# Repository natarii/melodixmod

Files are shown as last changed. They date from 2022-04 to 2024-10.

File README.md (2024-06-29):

MelodixMod
========
The MelodixMod project adds internal memory to the TOA MELODIX ML-304 melody generator. This repository also contains WIP hardware and software documentation for the original device.

## Overview
ML-304 devices use a Yamaha YM2203 OPN FM sound source to play back melodies, chimes and tones stored on memory cards. The MelodixMod system serves as an effective replacement for these cards. Full function of the original unit is retained -- physical cards inserted into the slots will override any data stored on MelodixMod's flash. A bank switching option is available through a hole on the rear panel which allows the user to switch between multiple banks of simulated cards. Impact to the device's appearance is also minimized, with the only change visible from the outside being the removal of a grounding screw.

### Mod Files
- `Logic` - Data to program the mod's decode logic chip
- `MCU` - Program for the mod's ATTiny85 MCU
- `PCB` - EAGLE schematic and PCB design files
- `PCBSpacer` - OpenSCAD design file and STL for a 3D-printable spacer to support the mod PCB

### Research Files
- `Disassembly` - Original ML-304 program disassembly
- `FujisokuBProgrammer` Arduino Mega-based programmer for Melodix cards
- `MelodixCard` - Information about the data format on Melodix cards




## MELODIX CARD information

The memory cards used in the ML-304 are pre-programmed and follow the Fujisoku B-series physical and electrical standard. Despite a very vague resemblance to PCMCIA and other common memory cards, this is an obsolete and relatively rare format. As the Melodix units are niche in addition to not having been marketed outside of Japan, original TOA cards fetch prices in the hundreds of USD range on auction sites, making it infeasible for most (certainly me!) to collect any more than the less-desirable cards.

## Why making reproduction cards isn't viable

Fujisoku B-series cards use very thin contacts on the card side, which mate with "forks" in the slot. A reproduction card could likely be made out of very thin PCB, but there is not much remaining height for components on the board. Surface mount parts may be viable (assuming a programmer which the cards could slot into existed -- more on that later), but any through-hole parts like socketed memory would not be usable without hanging further than usual out of the front of the device (outside of the normal card form factor).

UV EPROM, EEPROM, flash, and SRAM-based B-series cards were produced, but these are also becoming increasingly difficult to find. As these cards are writable, they also require hardware modifications to the Melodix unit as it does not drive all of the control lines they need.

## Card slot availability

In 2021, the availability of B-series card slots was essentially nil. An exhaustive personal and crowdsourced search turned up no supplies of slots, aside from ones that could be removed from an existing piece of equipment. I was also not able to establish an actual part number or manufacturer for the slots.

In 2023, some slots have turned up on US eBay. I also found further documentation which reveals some card slot part numbers, which are listed below. Note that not all of these are usable as replacements in the original device, but could be used in an external programmer or dumping tool.

- ITT Cannon 990-2000-053 (right angle pins)
- ITT Cannon DICMI-38S-RPC-01 (right angle pins)
- Hakuto BC1R (right angle pins)
- Hakuto BC1S (straight pins)

Regardless of any current availability of card slots, they are no longer being produced and supplies will eventually run out. This is another nail in the coffin for using the programmable variants as reproduction cards.

## I made a reproduction card anyway

Before deciding to proceed with an internal card modification, I ended up purchasing an SRAM card and designing an Arduino Mega-based programmer for it. The programmer can connect to the Mega board with no extra components needed, and the code allows for card memory to be uploaded and downloaded via XMODEM. I also performed the required modifications to the Melodix PCB to allow SRAM cards to be used.

It is also possible to adapt these cards to be used in a standard EPROM programmer.

## Related WIP projects / TODO

  * Verify v1.1 mod PCB
  * Disassembly of ML-304/ML-301 MCU program (nearly complete, needs some updates now that I have the hardware to reference, also needs to be done in proper f9dasm format rather than simple text find-and-replace)
  * MAME driver for Melodix series (working, needs better integration with MAME cartridge system, needs UI)
  * Melodix card to VGM conversion utility (working, needs cleanup but otherwise complete)
  * MIDI to Melodix card conversion utility (partially working)
  * Replacement main MCU (not started)
  * Document the process to prepare data for MelodixMod's flash (really just concatenate 32KByte binaries)

## Acknowledgements
  * Thanks to Hind for providing the initial MCU ROM dump.

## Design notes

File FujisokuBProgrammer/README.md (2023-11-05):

This is a very quick and dirty program to be used with an Arduno Mega which allows reading and writing memory cards using XMODEM.

Wiring diagram can be divined from the code. Open the serial port at 115200 baud and issue the '?' character for usage information.

Please be cautious when using this tool as some commands will permanently destroy data without any warning or confirmation.

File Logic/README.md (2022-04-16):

A dedicated flash IC is used to implement chip select and bank switching logic.

A pre-built flash image is included, but a new one can be built using the PHPPLD project. This image is generated for up to 4 megabit flash, but can be written (with the higher unused area ignored) to 1 and 2 megabit parts.

`php <path to PHPPLD> -i 19 -w logic.bin logic.php`

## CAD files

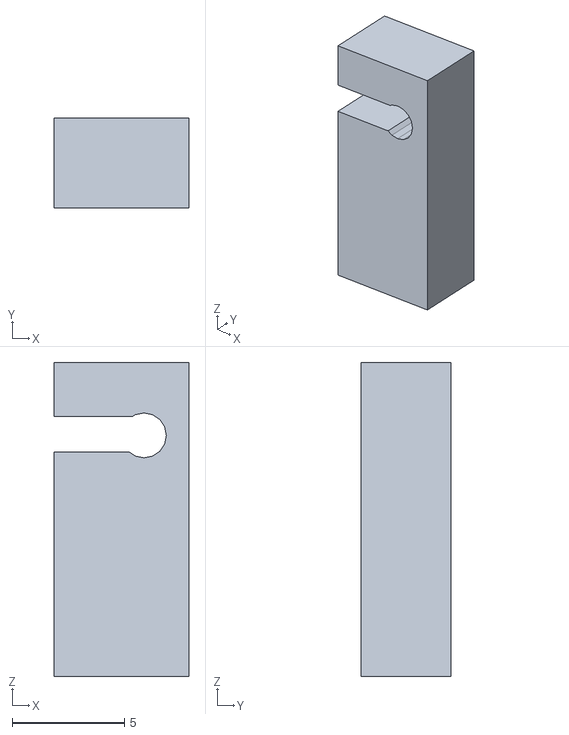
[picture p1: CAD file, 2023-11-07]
PCBSpacer/MelodixModPCBSpacer.stl
6.00 x 4.00 x 14.0

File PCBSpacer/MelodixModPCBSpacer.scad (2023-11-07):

$fn = 16;
difference() {
    union() {
        cube([6,4,10]);
        translate([0,0,10]) cube([6,4,4]);
    }
    translate([0,0,10]) cube([4,4,1.6]);
    translate([4,0,10.75]) rotate([-90,0,0]) cylinder(r=1, h=99, center=true);
}

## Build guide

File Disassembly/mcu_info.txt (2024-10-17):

*f9dasm base config
option 6301
file mcu.bin f000

*regions
data f000-f015 *scale lut
hex f000-f015
const f19a-f19b
const f1ae-f1af
const f210-f211
const f23d-f23e
const f259-f25a
const f272-f273
const f28b-f28c
const f2a4-f2a5
const f2bd-f2be
const f2d6-f2d7
const f382-f383
const f398-f399
const f3b0-f3b1
const f3fe-f3ff
const f8bd-f8be
const f983-f984
const f978-f979
const f9f7-f9f8
const fa1d-fa1e
const fa4b-fa4c
unused fbfb-fcff
word fd00-fd03 *ml301 tune addrs
data fd04-fd35 *ml301 tune patches
word fd36-fd3b *ml301 4-note chime patch addrs
word fd3c-fd41 *ml301 4-note chime track addrs
data fd42-fd75 *ml301 4-note chime track data
word fd76-fd7b *ml301 westminster patch addrs
word fd7c-fd81 *ml301 westminster track addrs
data fd82-fea5 *ml301 westminster track data
unused fea6-ffef

*labels
*mcu internal periphs
label 0000 DDR1
label 0001 DDR2
label 0002 PORT1
label 0003 PORT2
label 0004 DDR3
label 0005 DDR4
label 0007 PORT4
label 0008 TIMERCTL
label 0009 TIMERCNTHI
label 000a TIMERCNTLO *not used
label 000b TIMEROCRHI *not used
label 000d INTCAPHI *not used
label 000f PORT3CTL *not used
label 0010 RATEMODECTL *not used
label 0014 RAMCTL *not used
*vars
label 0080 track1_loc_word
label 0082 track2_loc_word
label 0084 track3_loc_word
label 0086 opn_ch
label 0087 track1_is_finished
label 0088 track2_is_finished
label 0089 track3_is_finished
label 008a opn_timer_b
label 008c track1_note_len
label 008d track2_note_len
label 008e track3_note_len
label 008f track1_kon_len
label 0090 track2_kon_len
label 0091 track3_kon_len
label 0092 patch_upload_tmp
label 0093 fb_algo_base
label 0096 tl_op1_base
label 0099 tl_op2_base
label 009c tl_op3_base
label 009f tl_op4_base
label 00a2 tl_op1
label 00a3 tl_op2
label 00a4 tl_op3
label 00a5 tl_op4
label 00a6 cur_note_freq
label 00a7 unused1
label 00a8 opn_tl_modifier
label 00a9 card_pointer
label 00ab opn_io_a_val
label 00ac active_card_slot
label 00ad tune_repeat_count
label 00ae tune_repeat_delay
label 00af tune_end_repeat_counter
label 00b0 tune_end_delay
label 00b1 patch_loc_word
label 00b3 int_flag
label 00b4 already_playing
label 00b5 currently_playing_bitfield
label 00b6 pressed_switch_bitfield
label 00b7 port1_isr_tmp
label 00b8 nothing_pressed_in_isr
label 00b9 tune_found_ff_flag
label 00ba unk_M00BA
label 00bc ml301_tune_rd_addr
label 00be ml301_is_4note
label 0100 opn_reg
label 0101 ml304_card_d_data_ml301_opn_data
label 0102 card_c_data
label 0103 card_b_data
label 0104 card_a_data
label 0105 card_addr
label 0140 opn_data
*code
label f000 scale_lut
label f05a mainloop
label f0b4 sel_card_at_104
label f0cf sel_card_at_103
label f0ed sel_card_at_102
label f10b sel_card_at_101
label f129 sel2_card_at_104
label f147 sel2_card_at_103
label f165 sel2_card_at_102
label f183 sel2_card_at_101
label f460 stop_track
label f490 opn_write
label f4af opn_read
label f4cb read_tune_data
label f6d2 load_ch_patch
label f565 opn_write_4op_tl
label f5c8 opn_keyon
label f5d2 opn_keyoff
label f5dc opn_write_freq
label f604 opn_timerb_setup
label f648 ml304_setup_next_note_trk1
label f68f ml304_setup_next_note_trk2
label f6d6 ml304_setup_next_note_trk3
label f71d add_opn_ch_x
label f72a spin_delay_100ms
label f7c0 isr_swi3_exit
label f7c9 isr_swi3_nothing_pressed
label f830 ml301_mode
label f869 ml301_clear
label f8bc ml301_setup_tune
label f954 ml301_setup_westminster
label f977 ml301_setup_westminster_2s_delay
label f982 ml301_setup_westminster_4s_delay
label fb2e ml301_setup_next_note_trk1
label fb5d ml301_setup_next_note_trk2
label fb8c ml301_setup_next_note_trk3
label fbbb ml301_swi_isr
label fd00 ml301_4notechime_addr
label fd02 ml301_westminster_addr
label fd04 ml301_4notechime_patch
label fd1d ml301_westminster_patch
label fd36 ml301_4notechime_data
label fd4a ml301_4notechime_trk1
label fd5a ml301_4notechime_trk2
label fd66 ml301_4notechime_trk3
label fd76 ml301_westminster_data
label fd8a ml301_westminster_trk1
label fde6 ml301_westminster_trk2
label fe46 ml301_westminster_trk3

*comments
*vars
lcomment 000a-0014 not used
lcomment 0096-009f note: stored in order 1234 here!!!
lcomment 00a2-00a5 note: stored in order 1234 here!!!
lcomment 00b6 really just a backup of PORT1
lcomment 00b9 can use FF instead of FE to terminate tune?
lcomment 00ba some temp var, holds a backup of X, -> 00BB
lcomment 0101 actually opn data on ml301 (different memory map)
lcomment 0105 16 bit wide, big endian, latched on hardware
lcomment 0140 MCU A6 -> OPN A0 on hardware
*code
lcomment f018 ml-304 bit
lcomment f034 prescaler
lcomment f03b ssg enable
lcomment f03e probably all off 1111
lcomment f042 io a
lcomment f063 redundant, it is written before reading in swi isr
lcomment f1a1 card presence detect
lcomment f1b3 enable TOI
lcomment f1bb io a
lcomment f1c3 mux select
lcomment f1cb mux select
lcomment f1ce card header
lcomment f1d3 relay off
lcomment f1d6 jmp skip start delay
lcomment f1d9 relay on
lcomment f1dc io b
lcomment f1de read start delay bits
lcomment f23c track 1 loc
lcomment f258 patch 1 loc
lcomment f271 track 2 loc
lcomment f28a patch 2 loc
lcomment f2a3 track 3 loc
lcomment f2bc patch 3 loc
lcomment f2d5 timer B val
lcomment f2e7 write timer A/B control and 3ch mode
lcomment f378 clear timer b flag, stop timer b
lcomment f3d6 probably all off 1111
lcomment f3da io a
lcomment f3dd disable TOI
lcomment f3fa write timer A/B control and 3ch mode
lcomment f40c probably all off 1111
lcomment f410 io a
lcomment f413 disable TOI
lcomment f41d big tree to check if trying to play same card already playing?
lcomment f477 write timer A/B control and 3ch mode
lcomment f47a probably all off 1111
lcomment f47e io a
lcomment f481 disable TOI
lcomment f4a3 bra if ml301
lcomment f4c1 bra if ml301
lcomment f4e1 drt/mul
lcomment f4fc write algo+fb
lcomment f504 first tl in patch (patch loc + 4)
lcomment f52c fb/algo (patch loc + 0x18)
lcomment f56d all of these CMPAs are to write TL only for slot operators
lcomment f5ac BUG!!! should be $44
lcomment f5df shl a <- b
lcomment f5eb x+=b
lcomment f5f1 a+=b
lcomment f5f6 freq hi
lcomment f600 freq lo
lcomment f608 a = ff - timerb
lcomment f60b a /= 8
lcomment f610 a = io port b
lcomment f613 a >>= 1
lcomment f614 a &= 0xf
lcomment f618 bra rts
lcomment f61e bra use normal value
lcomment f62f bra write A
lcomment f63e bra write A
lcomment f640 use normal value
lcomment f642 write A
lcomment f644 timer b
lcomment f73e clear timer b flag
lcomment f744 bra if ml301
lcomment f77e bra if ml304
lcomment f78b bra if nothing pressed
lcomment f7c0-f7c2 clear TOF
lcomment f827 all bra here if selected card is already playing?
lcomment f846 prescaler
lcomment f84d ssg enable
lcomment f854 io a
lcomment f8b4 io a
lcomment f8c1 enable TOI
lcomment f941 io a
lcomment f947 io b
lcomment f9ef timer ab ctl 3ch mode
lcomment f9f6 post-westminster delay
lcomment fa13 io a
lcomment fa16 disable TOI
lcomment fa47 timer ab ctl 3ch mode
lcomment fa57 io a
lcomment fa5a disable TOI
lcomment fa84 dt/mul
lcomment fa9b fb/conn
lcomment faf5 reading tempo here for ml301
lcomment fb2a timer b
lcomment fbcc-fbce clear TOF
lcomment fd04 same patch for all three tracks
lcomment fd1d same patch for all three tracks

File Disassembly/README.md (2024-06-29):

**Note:** `mcu.asm` is a generated file. Labels, comments, etc are configured in mcu_info.txt and then the f9dasm program is used to generate the disassembly from the info file and MCU ROM dump. You can generate the disassembly using the following command: `f9dasm -out mcu.asm -info mcu_info.txt`

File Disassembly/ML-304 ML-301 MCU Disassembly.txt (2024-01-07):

./f9dasm -offset f000 -6301  ../TOA\ Melodix/ML-30x\ Series/MCU/HD63B01V1P.bin > mcu.txt

vectors:
FFFE    !RES    F018
FFEE    TRAP    FFFF
FFFC    !NMI    F018
FFFA    SWI     F018
FFF8    !IRQ    F737
FFF6    ICF     F018
FFF4    OCF     F018
FFF2    TOF     F77B
FFF0    SCI     F018

opn and mcu clock is shared 4mhz, xtal + 74'04
mcu has a divide-by-4 internally

opn io:
a:
7 unused
6 unused
5 unused
4 unused
3 ML304B card A LED
2 ML304B card B LED
1 ML304B card C LED, ML301B chime LED
0 ML304B card D LED, ML301B westminster LED
(all active low on mcu, inverted on hw)
b:
7 0sec startup delay, active low
6 2sec startup delay, active low
5 4sec startup delay, active low
4 tempo MSbit
3 tempo
2 tempo
1 tempo LSbit
0 unknown
tempo is inverted on ml301, normal on ml304. valid range 0~9, 5 is normal
other hardware selects which tempo control to use on ml304. selected by the "LED" lines

mcu ports:
port1:
(used for switches, both front panel switch and rear inputs are on this port, unknown yet which switch is which bit)
ml304: all input
ml301: bits 6~4 are output...
active low
on ml301, bit 0 needs to be set and bit 7 needs to be clear to prevent it starting immediately. then bit 0 selects westminster and 1 selects 4note chime
00001011 makes it not play anything
7 ML304 front panel switch A
6 ML304 front panel switch B
5 ML304 front panel switch C
4 ML304 front panel switch D
3 ML304 rear terminal D
2 ML304 rear terminal C
1 ML304 rear terminal B
0 ML304 rear terminal A

port2:
7 unused
6 unused
5 unused
4 unused
3 remote relay, active high
2 volume mux B
1 unused
0 volume mux A
mux card select values:
card A: 3
card B: 0
card C: 1
card D: 2
port4:
7 high = ml304 mode, low = ml301
6 unused
5 unused
4 unused
3 unused
2 unused
1 unused
0 unused

mysteries:
- 0 second start delay jumper is unknown on ml301, but 99.9% bit 7
- options byte at start of card - might control remote relay behavior - MC-S01 has no delay no matter settings
  - bit 1 NOT set = no startup delay, no relay
  - bit 7 NOT set = will not play card. card detect, since the bus is pulled up on hardware?
- how are empty card slots detected? just bit 7 of first byte?
- port1 on ml304 split for front panel switch vs rear switch input, or something like that? which is which?
- ml301 port1 switch confusion
- ml301 port1 bits 6~4 are output... used for anything?

f9dasm: M6800/1/2/3/8/9 / H6309 Binary/OS9/FLEX9 Disassembler V1.80
Loaded binary file ../TOA Melodix/ML-30x Series/MCU/HD63B01V1P.bin

;****************************************************
;* Used Labels                                      *
;****************************************************

DDR1   EQU     $0000
DDR2   EQU     $0001
PORT1   EQU     $0002
PORT2   EQU     $0003
DDR3   EQU     $0004
DDR4   EQU     $0005
PORT4   EQU     $0007
TIMERCTL   EQU     $0008
TIMERCNTHI   EQU     $0009
TIMERCNTLO   EQU     $000A
TIMEROCRHI   EQU     $000B ;not used
INTCAPHI   EQU     $000D ;not used
PORT3CTL   EQU     $000F ;not used
RATEMODECTL   EQU     $0010 ;not used
RAMCTL   EQU     $0014 ;not used
track1_loc_word   EQU     $0080
track2_loc_word   EQU     $0082
track3_loc_word   EQU     $0084
opn_ch   EQU     $0086
track1_is_finished   EQU     $0087
track2_is_finished   EQU     $0088
track3_is_finished   EQU     $0089
opn_timer_b   EQU     $008A
M008B   EQU     $008B
track1_note_len   EQU     $008C
track2_note_len   EQU     $008D
track3_note_len   EQU     $008E
track1_kon_len   EQU     $008F
track2_kon_len   EQU     $0090
track3_kon_len   EQU     $0091
patch_upload_tmp   EQU     $0092
fb_algo_base   EQU     $0093
tl_op1_base   EQU     $0096 ;note: stored in order 1234 here!!!
tl_op2_base   EQU     $0099
tl_op3_base   EQU     $009C
tl_op4_base   EQU     $009F
tl_op1   EQU     $00A2 ;note: stored in order 1234 here!!!
tl_op2   EQU     $00A3
tl_op3   EQU     $00A4
tl_op4   EQU     $00A5
cur_note_freq   EQU     $00A6
unused1   EQU     $00A7
opn_tl_modifier   EQU     $00A8
card_pointer   EQU     $00A9
opn_io_a_val   EQU     $00AB
active_card_slot   EQU     $00AC
tune_end_delay   EQU     $00AD
tune_end_delay_lo   EQU     $00AE
M00AF   EQU     $00AF
M00B0   EQU     $00B0 ;high byte of patch 1 loc???
patch_loc_word   EQU     $00B1
int_flag   EQU     $00B3
already_playing   EQU     $00B4
currently_playing_bitfield   EQU     $00B5
pressed_switch_bitfield   EQU     $00B6 ;really just a backup of PORT1
port1_isr_tmp   EQU     $00B7
nothing_pressed_in_isr   EQU     $00B8
tune_found_ff_flag   EQU     $00B9 ;can use FF instead of FE to terminate tune?
unk_M00BA   EQU     $00BA ;some temp var, holds a backup of X, -> 00BB
unk_M00BC   EQU     $00BC ;temp, stores offset into builtin tune or something like that
unk_M00BE   EQU     $00BE ;temp, some offset on ml301
M00BF   EQU     $00BF
M00C0   EQU     $00C0
M00C1   EQU     $00C1
M00FE   EQU     $00FE
M00FF   EQU     $00FF
opn_reg   EQU     $0100
card_d_data   EQU     $0101
card_c_data   EQU     $0102
card_b_data   EQU     $0103
card_a_data   EQU     $0104
card_addr   EQU     $0105 ;16 bit wide, big endian ($0106 is LSB). must be latched on hardware? (address ON the card)
opn_data_ml304   EQU     $0140 ;MCU A6 -> OPN A0 on hardware??? or something more complicated?

;****************************************************
;* Program Code / Data Areas                        *
;****************************************************

        ORG     $F000

scale_lut   FCB     $02                      ;F000: 02             '.' ;ignore all of this code up to $F017, none of it is valid code, it's just a LUT
        BSR     ZF005                    ;F001: 8D 02          '..'
        ANDA    M02DD                    ;F003: B4 02 DD       '...'
        FCB     $03                      ;F006: 03             '.'
        DEX                              ;F007: 09             '.'
        FCB     $03                      ;F008: 03             '.'
        PSHB                             ;F009: 37             '7'
        FCB     $03                      ;F00A: 03             '.'
        ASL     $03,X                    ;F00B: 68 03          'h.'
        CPX     PORT2                    ;F00D: 9C 03          '..'
        ADDD    DDR3                    ;F00F: D3 04          '..'
        SEC                              ;F011: 0D             '.'
        LSRD                             ;F012: 04             '.'
        FCB     $4B                      ;F013: 4B             'K'
        LSRD                             ;F014: 04             '.'
        CPX     #M04D1                   ;F015: 8C 04 D1       '...'
hdlr_RST TIM     #$80,PORT4               ;F018: 7B 80 07       '{..' ml-304 bit
        BNE     ZF020                    ;F01B: 26 03          '&.'
        JMP     ml301_mode                    ;F01D: 7E F8 30       '~.0'
ZF020   CLRA                             ;F020: 4F             'O'
        STAA    PORT1                    ;F021: 97 02          '..'
        STAA    PORT2                    ;F023: 97 03          '..'
        STAA    DDR1                    ;F025: 97 00          '..'
        LDAA    #$0D                     ;F027: 86 0D          '..'
        STAA    DDR2                    ;F029: 97 01          '..'
        LDAA    #$7F                     ;F02B: 86 7F          '..'
        STAA    DDR4                    ;F02D: 97 05          '..'
        LDS     #M00FF                   ;F02F: 8E 00 FF       '...'
        LDAB    #$2D                     ;F032: C6 2D          '.-'
        JSR     opn_write                    ;F034: BD F4 90       '...' prescaler
        LDAB    #$07                     ;F037: C6 07          '..'
        LDAA    #$7F                     ;F039: 86 7F          '..'
        JSR     opn_write                    ;F03B: BD F4 90       '...' ssg enable
        LDAA    #$0F                     ;F03E: 86 0F          '..' probably all off 1111
        LDAB    #$0E                     ;F040: C6 0E          '..'
        JSR     opn_write                    ;F042: BD F4 90       '...' io a
        CLRA                             ;F045: 4F             'O'
        STAA    opn_ch                    ;F046: 97 86          '..'
        JSR     opn_keyoff                    ;F048: BD F5 D2       '...'
        INC     >opn_ch                   ;F04B: 7C 00 86       '|..'
        JSR     opn_keyoff                    ;F04E: BD F5 D2       '...'
        INC     >opn_ch                   ;F051: 7C 00 86       '|..'
        JSR     opn_keyoff                    ;F054: BD F5 D2       '...'
        AIM     #$F7,PORT2               ;F057: 71 F7 03       'q..'
mainloop   CLRA                             ;F05A: 4F             'O'
        STAA    int_flag                    ;F05B: 97 B3          '..'
        STAA    already_playing                    ;F05D: 97 B4          '..'
        STAA    currently_playing_bitfield                    ;F05F: 97 B5          '..'
        STAA    pressed_switch_bitfield                    ;F061: 97 B6          '..'
        STAA    port1_isr_tmp                    ;F063: 97 B7          '..' redundant, it is written before reading in swi isr
        STAA    nothing_pressed_in_isr                    ;F065: 97 B8          '..'
        STAA    tune_found_ff_flag                    ;F067: 97 B9          '..'
        TIM     #$80,PORT1               ;F069: 7B 80 02       '{..'
        BNE     ZF071                    ;F06C: 26 03          '&.'
        JMP     ZF11E                    ;F06E: 7E F1 1E       '~..'
ZF071   TIM     #$01,PORT1               ;F071: 7B 01 02       '{..'
        BNE     ZF079                    ;F074: 26 03          '&.'
        JMP     ZF0AC                    ;F076: 7E F0 AC       '~..'
ZF079   TIM     #$40,PORT1               ;F079: 7B 40 02       '{@.'
        BNE     ZF081                    ;F07C: 26 03          '&.'
        JMP     ZF13C                    ;F07E: 7E F1 3C       '~.<'
ZF081   TIM     #$02,PORT1               ;F081: 7B 02 02       '{..'
        BNE     ZF089                    ;F084: 26 03          '&.'
        JMP     ZF0C7                    ;F086: 7E F0 C7       '~..'
ZF089   TIM     #$20,PORT1               ;F089: 7B 20 02       '{ .'
        BNE     ZF091                    ;F08C: 26 03          '&.'
        JMP     ZF15A                    ;F08E: 7E F1 5A       '~.Z'
ZF091   TIM     #$04,PORT1               ;F091: 7B 04 02       '{..'
        BNE     ZF099                    ;F094: 26 03          '&.'
        JMP     ZF0E2                    ;F096: 7E F0 E2       '~..'
ZF099   TIM     #$10,PORT1               ;F099: 7B 10 02       '{..'
        BNE     ZF0A1                    ;F09C: 26 03          '&.'
        JMP     ZF178                    ;F09E: 7E F1 78       '~.x'
ZF0A1   TIM     #$08,PORT1               ;F0A1: 7B 08 02       '{..'
        BNE     ZF0A9                    ;F0A4: 26 03          '&.'
        JMP     ZF100                    ;F0A6: 7E F1 00       '~..'
ZF0A9   JMP     mainloop                    ;F0A9: 7E F0 5A       '~.Z'
ZF0AC   JSR     spin_delay_100ms                    ;F0AC: BD F7 2A       '..*'
        TIM     #$01,PORT1               ;F0AF: 7B 01 02       '{..'
        BNE     mainloop                    ;F0B2: 26 A6          '&.'
sel_card_at_104   LDX     #card_a_data                   ;F0B4: CE 01 04       '...'
        STX     card_pointer                    ;F0B7: DF A9          '..'
        LDAA    #$07                     ;F0B9: 86 07          '..' 0111
        STAA    opn_io_a_val                    ;F0BB: 97 AB          '..'
        LDAA    #$00                     ;F0BD: 86 00          '..'
        STAA    active_card_slot                    ;F0BF: 97 AC          '..'
        OIM     #$01,pressed_switch_bitfield               ;F0C1: 72 01 B6       'r..'
        JMP     ZF196                    ;F0C4: 7E F1 96       '~..'
ZF0C7   JSR     spin_delay_100ms                    ;F0C7: BD F7 2A       '..*'
        TIM     #$02,PORT1               ;F0CA: 7B 02 02       '{..'
        BNE     mainloop                    ;F0CD: 26 8B          '&.'
sel_card_at_103   LDX     #card_b_data                   ;F0CF: CE 01 03       '...'
        STX     card_pointer                    ;F0D2: DF A9          '..'
        LDAA    #$0B                     ;F0D4: 86 0B          '..' 1011
        STAA    opn_io_a_val                    ;F0D6: 97 AB          '..'
        LDAA    #$03                     ;F0D8: 86 03          '..'
        STAA    active_card_slot                    ;F0DA: 97 AC          '..'
        OIM     #$02,pressed_switch_bitfield               ;F0DC: 72 02 B6       'r..'
        JMP     ZF196                    ;F0DF: 7E F1 96       '~..'
ZF0E2   JSR     spin_delay_100ms                    ;F0E2: BD F7 2A       '..*'
        TIM     #$04,PORT1               ;F0E5: 7B 04 02       '{..'
        BEQ     sel_card_at_102                    ;F0E8: 27 03          ''.'
        JMP     mainloop                    ;F0EA: 7E F0 5A       '~.Z'
sel_card_at_102   LDX     #card_c_data                   ;F0ED: CE 01 02       '...'
        STX     card_pointer                    ;F0F0: DF A9          '..'
        LDAA    #$0D                     ;F0F2: 86 0D          '..' 1101
        STAA    opn_io_a_val                    ;F0F4: 97 AB          '..'
        LDAA    #$01                     ;F0F6: 86 01          '..'
        STAA    active_card_slot                    ;F0F8: 97 AC          '..'
        OIM     #$04,pressed_switch_bitfield               ;F0FA: 72 04 B6       'r..'
        JMP     ZF196                    ;F0FD: 7E F1 96       '~..'
ZF100   JSR     spin_delay_100ms                    ;F100: BD F7 2A       '..*'
        TIM     #$08,PORT1               ;F103: 7B 08 02       '{..'
        BEQ     sel_card_at_101                    ;F106: 27 03          ''.'
        JMP     mainloop                    ;F108: 7E F0 5A       '~.Z'
sel_card_at_101   LDX     #card_d_data                   ;F10B: CE 01 01       '...'
        STX     card_pointer                    ;F10E: DF A9          '..'
        LDAA    #$0E                     ;F110: 86 0E          '..' 1110
        STAA    opn_io_a_val                    ;F112: 97 AB          '..'
        LDAA    #$02                     ;F114: 86 02          '..'
        STAA    active_card_slot                    ;F116: 97 AC          '..'
        OIM     #$08,pressed_switch_bitfield               ;F118: 72 08 B6       'r..'
        JMP     ZF196                    ;F11B: 7E F1 96       '~..'
ZF11E   JSR     spin_delay_100ms                    ;F11E: BD F7 2A       '..*'
        TIM     #$80,PORT1               ;F121: 7B 80 02       '{..'
        BEQ     sel2_card_at_104                    ;F124: 27 03          ''.'
        JMP     mainloop                    ;F126: 7E F0 5A       '~.Z'
sel2_card_at_104   LDX     #card_a_data                   ;F129: CE 01 04       '...'
        STX     card_pointer                    ;F12C: DF A9          '..'
        LDAA    #$07                     ;F12E: 86 07          '..' 0111
        STAA    opn_io_a_val                    ;F130: 97 AB          '..'
        LDAA    #$00                     ;F132: 86 00          '..'
        STAA    active_card_slot                    ;F134: 97 AC          '..'
        OIM     #$80,pressed_switch_bitfield               ;F136: 72 80 B6       'r..'
        JMP     ZF196                    ;F139: 7E F1 96       '~..'
ZF13C   JSR     spin_delay_100ms                    ;F13C: BD F7 2A       '..*'
        TIM     #$40,PORT1               ;F13F: 7B 40 02       '{@.'
        BEQ     sel2_card_at_103                    ;F142: 27 03          ''.'
        JMP     mainloop                    ;F144: 7E F0 5A       '~.Z'
sel2_card_at_103   LDX     #card_b_data                   ;F147: CE 01 03       '...'
        STX     card_pointer                    ;F14A: DF A9          '..'
        LDAA    #$0B                     ;F14C: 86 0B          '..' 1011
        STAA    opn_io_a_val                    ;F14E: 97 AB          '..'
        LDAA    #$03                     ;F150: 86 03          '..'
        STAA    active_card_slot                    ;F152: 97 AC          '..'
        OIM     #$40,pressed_switch_bitfield               ;F154: 72 40 B6       'r@.'
        JMP     ZF196                    ;F157: 7E F1 96       '~..'
ZF15A   JSR     spin_delay_100ms                    ;F15A: BD F7 2A       '..*'
        TIM     #$20,PORT1               ;F15D: 7B 20 02       '{ .'
        BEQ     sel2_card_at_102                    ;F160: 27 03          ''.'
        JMP     mainloop                    ;F162: 7E F0 5A       '~.Z'
sel2_card_at_102   LDX     #card_c_data                   ;F165: CE 01 02       '...'
        STX     card_pointer                    ;F168: DF A9          '..'
        LDAA    #$0D                     ;F16A: 86 0D          '..' 1101
        STAA    opn_io_a_val                    ;F16C: 97 AB          '..'
        LDAA    #$01                     ;F16E: 86 01          '..'
        STAA    active_card_slot                    ;F170: 97 AC          '..'
        OIM     #$20,pressed_switch_bitfield               ;F172: 72 20 B6       'r .'
        JMP     ZF196                    ;F175: 7E F1 96       '~..'
ZF178   JSR     spin_delay_100ms                    ;F178: BD F7 2A       '..*'
        TIM     #$10,PORT1               ;F17B: 7B 10 02       '{..'
        BEQ     sel2_card_at_101                    ;F17E: 27 03          ''.'
        JMP     mainloop                    ;F180: 7E F0 5A       '~.Z'
sel2_card_at_101   LDX     #card_d_data                   ;F183: CE 01 01       '...'
        STX     card_pointer                    ;F186: DF A9          '..'
        LDAA    #$0E                     ;F188: 86 0E          '..' 1110
        STAA    opn_io_a_val                    ;F18A: 97 AB          '..'
        LDAA    #$02                     ;F18C: 86 02          '..'
        STAA    active_card_slot                    ;F18E: 97 AC          '..'
        OIM     #$10,pressed_switch_bitfield               ;F190: 72 10 B6       'r..'
        JMP     ZF196                    ;F193: 7E F1 96       '~..'
ZF196   CLRA                             ;F196: 4F             'O'
        STAA    currently_playing_bitfield                    ;F197: 97 B5          '..'
        LDX     #$0000                   ;F199: CE 00 00       '...'
        STX     card_addr                    ;F19C: FF 01 05       '...'
        LDX     card_pointer                    ;F19F: DE A9          '..'
        TIM     #$80,$00,X               ;F1A1: 6B 80 00       'k..' card presence detect?
        BEQ     ZF1AC                    ;F1A4: 27 06          ''.'
        AIM     #$F7,PORT2               ;F1A6: 71 F7 03       'q..'
        JMP     mainloop                    ;F1A9: 7E F0 5A       '~.Z'
ZF1AC   PSHX                             ;F1AC: 3C             '<'
        LDX     #MFFFF                   ;F1AD: CE FF FF       '...'
        STX     TIMERCNTHI                    ;F1B0: DF 09          '..'
        PULX                             ;F1B2: 38             '8'
        OIM     #$04,TIMERCTL               ;F1B3: 72 04 08       'r..' enable TOI
        CLI                              ;F1B6: 0E             '.'
        LDAA    opn_io_a_val                    ;F1B7: 96 AB          '..'
        LDAB    #$0E                     ;F1B9: C6 0E          '..'
        JSR     opn_write                    ;F1BB: BD F4 90       '...' io a
        TIM     #$02,active_card_slot               ;F1BE: 7B 02 AC       '{..'
        BEQ     ZF1C6                    ;F1C1: 27 03          ''.'
        OIM     #$01,PORT2               ;F1C3: 72 01 03       'r..' mux select?
ZF1C6   TIM     #$01,active_card_slot               ;F1C6: 7B 01 AC       '{..'
        BEQ     ZF1CE                    ;F1C9: 27 03          ''.'
        OIM     #$04,PORT2               ;F1CB: 72 04 03       'r..' mux select?
ZF1CE   TIM     #$02,$00,X               ;F1CE: 6B 02 00       'k..' card header
        BNE     ZF1D9                    ;F1D1: 26 06          '&.'
        AIM     #$F7,PORT2               ;F1D3: 71 F7 03       'q..' relay off
        JMP     ZF20F                    ;F1D6: 7E F2 0F       '~..' jmp skip start delay
ZF1D9   OIM     #$08,PORT2               ;F1D9: 72 08 03       'r..' relay on
        LDAB    #$0F                     ;F1DC: C6 0F          '..' io b
        JSR     opn_read                    ;F1DE: BD F4 AF       '...' read start delay bits
        BITA    #$20                     ;F1E1: 85 20          '. '
        BEQ     ZF1EB                    ;F1E3: 27 06          ''.'
        BITA    #$40                     ;F1E5: 85 40          '.@'
        BEQ     ZF1FD                    ;F1E7: 27 14          ''.'
        BRA     ZF20F                    ;F1E9: 20 24          ' $'
ZF1EB   LDAA    #$28                     ;F1EB: 86 28          '.('
ZF1ED   TIM     #$01,already_playing               ;F1ED: 7B 01 B4       '{..'
        BEQ     ZF1F5                    ;F1F0: 27 03          ''.'
        JMP     ZF3E3                    ;F1F2: 7E F3 E3       '~..'
ZF1F5   JSR     spin_delay_100ms                    ;F1F5: BD F7 2A       '..*'
        DECA                             ;F1F8: 4A             'J'
        BNE     ZF1ED                    ;F1F9: 26 F2          '&.'
        BRA     ZF20F                    ;F1FB: 20 12          ' .'
ZF1FD   LDAA    #$14                     ;F1FD: 86 14          '..'
ZF1FF   TIM     #$01,already_playing               ;F1FF: 7B 01 B4       '{..'
        BEQ     ZF207                    ;F202: 27 03          ''.'
        JMP     ZF3E3                    ;F204: 7E F3 E3       '~..'
ZF207   JSR     spin_delay_100ms                    ;F207: BD F7 2A       '..*'
        DECA                             ;F20A: 4A             'J'
        BNE     ZF1FF                    ;F20B: 26 F2          '&.'
        BRA     ZF20F                    ;F20D: 20 00          ' .' w
ZF20F   LDX     #$0001                   ;F20F: CE 00 01       '...'
        STX     card_addr                    ;F212: FF 01 05       '...'
        JSR     read_tune_data                    ;F215: BD F4 CB       '...'
        STAA    tune_end_delay                    ;F218: 97 AD          '..'
        INX                              ;F21A: 08             '.'
        STX     card_addr                    ;F21B: FF 01 05       '...'
        JSR     read_tune_data                    ;F21E: BD F4 CB       '...'
        STAA    tune_end_delay_lo                    ;F221: 97 AE          '..'
        INX                              ;F223: 08             '.'
        STX     card_addr                    ;F224: FF 01 05       '...'
        JSR     read_tune_data                    ;F227: BD F4 CB       '...'
        STAA    M00B0                    ;F22A: 97 B0          '..'
        JMP     ZF22F                    ;F22C: 7E F2 2F       '~./'
ZF22F   CLRA                             ;F22F: 4F             'O'
        STAA    track1_note_len                    ;F230: 97 8C          '..'
        STAA    track2_note_len                    ;F232: 97 8D          '..'
        STAA    track3_note_len                    ;F234: 97 8E          '..'
        STAA    track1_kon_len                    ;F236: 97 8F          '..'
        STAA    track2_kon_len                    ;F238: 97 90          '..'
        STAA    track3_kon_len                    ;F23A: 97 91          '..'
        LDX     #$000b                   ;F23C: CE 00 0B       '...' track 1 loc
        STX     card_addr                    ;F23F: FF 01 05       '...'
        JSR     read_tune_data                    ;F242: BD F4 CB       '...'
        TAB                              ;F245: 16             '.'
        DEX                              ;F246: 09             '.'
        STX     card_addr                    ;F247: FF 01 05       '...'
        JSR     read_tune_data                    ;F24A: BD F4 CB       '...'
        STD     track1_loc_word                    ;F24D: DD 80          '..'
        BNE     ZF254                    ;F24F: 26 03          '&.'
        JMP     ZF2EC                    ;F251: 7E F2 EC       '~..'
ZF254   LDAA    #$00                     ;F254: 86 00          '..'
        STAA    opn_ch                    ;F256: 97 86          '..'
        LDX     #$0005                   ;F258: CE 00 05       '...' patch 1 loc
        STX     card_addr                    ;F25B: FF 01 05       '...'
        JSR     read_tune_data                    ;F25E: BD F4 CB       '...'
        TAB                              ;F261: 16             '.'
        DEX                              ;F262: 09             '.'
        STX     card_addr                    ;F263: FF 01 05       '...'
        JSR     read_tune_data                    ;F266: BD F4 CB       '...'
        STD     patch_loc_word                    ;F269: DD B1          '..'
        JSR     load_ch_patch                    ;F26B: BD F4 D2       '...'
        CLRA                             ;F26E: 4F             'O'
        STAA    track1_is_finished                    ;F26F: 97 87          '..'
ZF271   LDX     #$000d                   ;F271: CE 00 0D       '...' track 2 loc
        STX     card_addr                    ;F274: FF 01 05       '...'
        JSR     read_tune_data                    ;F277: BD F4 CB       '...'
        TAB                              ;F27A: 16             '.'
        DEX                              ;F27B: 09             '.'
        STX     card_addr                    ;F27C: FF 01 05       '...'
        JSR     read_tune_data                    ;F27F: BD F4 CB       '...'
        STD     track2_loc_word                    ;F282: DD 82          '..'
        BEQ     ZF2F3                    ;F284: 27 6D          ''m'
        LDAA    #$01                     ;F286: 86 01          '..'
        STAA    opn_ch                    ;F288: 97 86          '..'
        LDX     #$0007                   ;F28A: CE 00 07       '...' patch 2 loc
        STX     card_addr                    ;F28D: FF 01 05       '...'
        JSR     read_tune_data                    ;F290: BD F4 CB       '...'
        TAB                              ;F293: 16             '.'
        DEX                              ;F294: 09             '.'
        STX     card_addr                    ;F295: FF 01 05       '...'
        JSR     read_tune_data                    ;F298: BD F4 CB       '...'
        STD     patch_loc_word                    ;F29B: DD B1          '..'
        JSR     load_ch_patch                    ;F29D: BD F4 D2       '...'
        CLRA                             ;F2A0: 4F             'O'
        STAA    track2_is_finished                    ;F2A1: 97 88          '..'
ZF2A3   LDX     #$000f                   ;F2A3: CE 00 0F       '...' track 3 loc
        STX     card_addr                    ;F2A6: FF 01 05       '...'
        JSR     read_tune_data                    ;F2A9: BD F4 CB       '...'
        TAB                              ;F2AC: 16             '.'
        DEX                              ;F2AD: 09             '.'
        STX     card_addr                    ;F2AE: FF 01 05       '...'
        JSR     read_tune_data                    ;F2B1: BD F4 CB       '...'
        STD     track3_loc_word                    ;F2B4: DD 84          '..'
        BEQ     ZF2FA                    ;F2B6: 27 42          ''B'
        LDAA    #$02                     ;F2B8: 86 02          '..'
        STAA    opn_ch                    ;F2BA: 97 86          '..'
        LDX     #$0009                   ;F2BC: CE 00 09       '...' patch 3 loc
        STX     card_addr                    ;F2BF: FF 01 05       '...'
        JSR     read_tune_data                    ;F2C2: BD F4 CB       '...'
        TAB                              ;F2C5: 16             '.'
        DEX                              ;F2C6: 09             '.'
        STX     card_addr                    ;F2C7: FF 01 05       '...'
        JSR     read_tune_data                    ;F2CA: BD F4 CB       '...'
        STD     patch_loc_word                    ;F2CD: DD B1          '..'
        JSR     load_ch_patch                    ;F2CF: BD F4 D2       '...'
        CLRA                             ;F2D2: 4F             'O'
        STAA    track3_is_finished                    ;F2D3: 97 89          '..'
ZF2D5   LDX     #$0010                   ;F2D5: CE 00 10       '...' timer B val
        STX     card_addr                    ;F2D8: FF 01 05       '...'
        JSR     read_tune_data                    ;F2DB: BD F4 CB       '...'
        STAA    opn_timer_b                    ;F2DE: 97 8A          '..'
        JSR     opn_timerb_setup                    ;F2E0: BD F6 04       '...'
        LDAA    #$2A                     ;F2E3: 86 2A          '.*'
        LDAB    #$27                     ;F2E5: C6 27          '.''
        JSR     opn_write                    ;F2E7: BD F4 90       '...' write timer A/B control and 3ch mode
        BRA     ZF301                    ;F2EA: 20 15          ' .'
ZF2EC   LDAA    #$FF                     ;F2EC: 86 FF          '..'
        STAA    track1_is_finished                    ;F2EE: 97 87          '..'
        JMP     ZF271                    ;F2F0: 7E F2 71       '~.q'
ZF2F3   LDAA    #$FF                     ;F2F3: 86 FF          '..'
        STAA    track2_is_finished                    ;F2F5: 97 88          '..'
        JMP     ZF2A3                    ;F2F7: 7E F2 A3       '~..'
ZF2FA   LDAA    #$FF                     ;F2FA: 86 FF          '..'
        STAA    track3_is_finished                    ;F2FC: 97 89          '..'
        JMP     ZF2D5                    ;F2FE: 7E F2 D5       '~..'
ZF301   OIM     #$01,int_flag               ;F301: 72 01 B3       'r..'
        WAI                              ;F304: 3E             '>'
        TIM     #$01,int_flag               ;F305: 7B 01 B3       '{..'
        BNE     ZF301                    ;F308: 26 F7          '&.'
        LDAA    already_playing                    ;F30A: 96 B4          '..'
        BEQ     ZF311                    ;F30C: 27 03          ''.'
        JMP     ZF3E3                    ;F30E: 7E F3 E3       '~..'
ZF311   LDAA    #$00                     ;F311: 86 00          '..'
        STAA    opn_ch                    ;F313: 97 86          '..'
        LDAA    track1_note_len                    ;F315: 96 8C          '..'
        BNE     ZF327                    ;F317: 26 0E          '&.'
        LDAA    track1_is_finished                    ;F319: 96 87          '..'
        BNE     ZF32E                    ;F31B: 26 11          '&.'
        JSR     ml304_setup_next_note_trk1                    ;F31D: BD F6 48       '..H'
        LDAA    tune_found_ff_flag                    ;F320: 96 B9          '..'
        BEQ     ZF327                    ;F322: 27 03          ''.'
        JMP     stop_track                    ;F324: 7E F4 60       '~.`'
ZF327   LDAA    track1_kon_len                    ;F327: 96 8F          '..'
        BNE     ZF32E                    ;F329: 26 03          '&.'
        JSR     opn_keyoff                    ;F32B: BD F5 D2       '...'
ZF32E   LDAA    #$01                     ;F32E: 86 01          '..'
        STAA    opn_ch                    ;F330: 97 86          '..'
        LDAA    track2_note_len                    ;F332: 96 8D          '..'
        BNE     ZF344                    ;F334: 26 0E          '&.'
        LDAA    track2_is_finished                    ;F336: 96 88          '..'
        BNE     ZF34B                    ;F338: 26 11          '&.'
        JSR     ml304_setup_next_note_trk2                    ;F33A: BD F6 8F       '...'
        LDAA    tune_found_ff_flag                    ;F33D: 96 B9          '..'
        BEQ     ZF344                    ;F33F: 27 03          ''.'
        JMP     stop_track                    ;F341: 7E F4 60       '~.`'
ZF344   LDAA    track2_kon_len                    ;F344: 96 90          '..'
        BNE     ZF34B                    ;F346: 26 03          '&.'
        JSR     opn_keyoff                    ;F348: BD F5 D2       '...'
ZF34B   LDAA    #$02                     ;F34B: 86 02          '..'
        STAA    opn_ch                    ;F34D: 97 86          '..'
        LDAA    track3_note_len                    ;F34F: 96 8E          '..'
        BNE     ZF361                    ;F351: 26 0E          '&.'
        LDAA    track3_is_finished                    ;F353: 96 89          '..'
        BNE     ZF368                    ;F355: 26 11          '&.'
        JSR     ml304_setup_next_note_trk3                    ;F357: BD F6 D6       '...'
        LDAA    tune_found_ff_flag                    ;F35A: 96 B9          '..'
        BEQ     ZF361                    ;F35C: 27 03          ''.'
        JMP     stop_track                    ;F35E: 7E F4 60       '~.`'
ZF361   LDAA    track3_kon_len                    ;F361: 96 91          '..'
        BNE     ZF368                    ;F363: 26 03          '&.'
        JSR     opn_keyoff                    ;F365: BD F5 D2       '...'
ZF368   LDAA    track1_is_finished                    ;F368: 96 87          '..'
        BEQ     ZF301                    ;F36A: 27 95          ''.'
        LDAA    track2_is_finished                    ;F36C: 96 88          '..'
        BEQ     ZF301                    ;F36E: 27 91          ''.'
        LDAA    track3_is_finished                    ;F370: 96 89          '..'
        BEQ     ZF301                    ;F372: 27 8D          ''.'
        LDAA    #$28                     ;F374: 86 28          '.('
        LDAB    #$27                     ;F376: C6 27          '.''
        JSR     opn_write                    ;F378: BD F4 90       '...' clear timer b flag, stop timer b
        LDAA    M00B0                    ;F37B: 96 B0          '..'
        BEQ     ZF397                    ;F37D: 27 18          ''.'
        STAA    M00AF                    ;F37F: 97 AF          '..'
ZF381   LDX     #$000a                   ;F381: CE 00 0A       '...'
ZF384   TIM     #$01,already_playing               ;F384: 7B 01 B4       '{..'
        BEQ     ZF38C                    ;F387: 27 03          ''.'
        JMP     ZF3E3                    ;F389: 7E F3 E3       '~..'
ZF38C   JSR     spin_delay_100ms                    ;F38C: BD F7 2A       '..*'
        DEX                              ;F38F: 09             '.'
        BNE     ZF384                    ;F390: 26 F2          '&.'
        DEC     >M00AF                   ;F392: 7A 00 AF       'z..'
        BNE     ZF381                    ;F395: 26 EA          '&.'
ZF397   LDX     #$0000                   ;F397: CE 00 00       '...'
        STX     card_addr                    ;F39A: FF 01 05       '...'
        LDX     card_pointer                    ;F39D: DE A9          '..'
        TIM     #$01,$00,X               ;F39F: 6B 01 00       'k..'
        BNE     ZF3C8                    ;F3A2: 26 24          '&$'
        DEC     >tune_end_delay                   ;F3A4: 7A 00 AD       'z..'
        BEQ     ZF3C8                    ;F3A7: 27 1F          ''.'
        LDAA    tune_end_delay_lo                    ;F3A9: 96 AE          '..'
        BEQ     ZF3C5                    ;F3AB: 27 18          ''.'
        STAA    M00AF                    ;F3AD: 97 AF          '..'
ZF3AF   LDX     #$000a                   ;F3AF: CE 00 0A       '...'
ZF3B2   TIM     #$01,already_playing               ;F3B2: 7B 01 B4       '{..'
        BEQ     ZF3BA                    ;F3B5: 27 03          ''.'
        JMP     ZF3E3                    ;F3B7: 7E F3 E3       '~..'
ZF3BA   JSR     spin_delay_100ms                    ;F3BA: BD F7 2A       '..*'
        DEX                              ;F3BD: 09             '.'
        BNE     ZF3B2                    ;F3BE: 26 F2          '&.'
        DEC     >M00AF                   ;F3C0: 7A 00 AF       'z..'
        BNE     ZF3AF                    ;F3C3: 26 EA          '&.'
ZF3C5   JMP     ZF22F                    ;F3C5: 7E F2 2F       '~./'
ZF3C8   LDAA    PORT1                    ;F3C8: 96 02          '..'
        COMA                             ;F3CA: 43             'C'
        BNE     ZF3D0                    ;F3CB: 26 03          '&.'
        AIM     #$F7,PORT2               ;F3CD: 71 F7 03       'q..'
ZF3D0   AIM     #$FE,PORT2               ;F3D0: 71 FE 03       'q..'
        AIM     #$FB,PORT2               ;F3D3: 71 FB 03       'q..'
        LDAA    #$0F                     ;F3D6: 86 0F          '..' probably all off 1111
        LDAB    #$0E                     ;F3D8: C6 0E          '..'
        JSR     opn_write                    ;F3DA: BD F4 90       '...' io a
        AIM     #$FB,TIMERCTL               ;F3DD: 71 FB 08       'q..' disable TOI
        JMP     mainloop                    ;F3E0: 7E F0 5A       '~.Z'
ZF3E3   LDAA    #$00                     ;F3E3: 86 00          '..'
        STAA    opn_ch                    ;F3E5: 97 86          '..'
        JSR     opn_keyoff                    ;F3E7: BD F5 D2       '...'
        INC     >opn_ch                   ;F3EA: 7C 00 86       '|..'
        JSR     opn_keyoff                    ;F3ED: BD F5 D2       '...'
        INC     >opn_ch                   ;F3F0: 7C 00 86       '|..'
        JSR     opn_keyoff                    ;F3F3: BD F5 D2       '...'
        LDAA    #$28                     ;F3F6: 86 28          '.('
        LDAB    #$27                     ;F3F8: C6 27          '.''
        JSR     opn_write                    ;F3FA: BD F4 90       '...' write timer A/B control and 3ch mode
        LDX     #DDR4                   ;F3FD: CE 00 05       '...'
ZF400   JSR     spin_delay_100ms                    ;F400: BD F7 2A       '..*'
        DEX                              ;F403: 09             '.'
        BNE     ZF400                    ;F404: 26 FA          '&.'
        AIM     #$FE,PORT2               ;F406: 71 FE 03       'q..'
        AIM     #$FB,PORT2               ;F409: 71 FB 03       'q..'
        LDAA    #$0F                     ;F40C: 86 0F          '..' probably all off 1111
        LDAB    #$0E                     ;F40E: C6 0E          '..'
        JSR     opn_write                    ;F410: BD F4 90       '...' io a
        AIM     #$FB,TIMERCTL               ;F413: 71 FB 08       'q..' disable TOI
        CLRA                             ;F416: 4F             'O'
        STAA    already_playing                    ;F417: 97 B4          '..'
        STAA    int_flag                    ;F419: 97 B3          '..'
        STAA    pressed_switch_bitfield                    ;F41B: 97 B6          '..'
        TIM     #$80,currently_playing_bitfield               ;F41D: 7B 80 B5       '{..' big tree to check if trying to play same card already playing?
        BEQ     ZF425                    ;F420: 27 03          ''.'
        JMP     sel2_card_at_104                    ;F422: 7E F1 29       '~.)'
ZF425   TIM     #$01,currently_playing_bitfield               ;F425: 7B 01 B5       '{..' 
        BEQ     ZF42D                    ;F428: 27 03          ''.'
        JMP     sel_card_at_104                    ;F42A: 7E F0 B4       '~..'
ZF42D   TIM     #$40,currently_playing_bitfield               ;F42D: 7B 40 B5       '{@.'
        BEQ     ZF435                    ;F430: 27 03          ''.'
        JMP     sel2_card_at_103                    ;F432: 7E F1 47       '~.G'
ZF435   TIM     #$02,currently_playing_bitfield               ;F435: 7B 02 B5       '{..'
        BEQ     ZF43D                    ;F438: 27 03          ''.'
        JMP     sel_card_at_103                    ;F43A: 7E F0 CF       '~..'
ZF43D   TIM     #$20,currently_playing_bitfield               ;F43D: 7B 20 B5       '{ .'
        BEQ     ZF445                    ;F440: 27 03          ''.'
        JMP     sel2_card_at_102                    ;F442: 7E F1 65       '~.e'
ZF445   TIM     #$04,currently_playing_bitfield               ;F445: 7B 04 B5       '{..'
        BEQ     ZF44D                    ;F448: 27 03          ''.'
        JMP     sel_card_at_102                    ;F44A: 7E F0 ED       '~..'
ZF44D   TIM     #$10,currently_playing_bitfield               ;F44D: 7B 10 B5       '{..'
        BEQ     ZF455                    ;F450: 27 03          ''.'
        JMP     sel2_card_at_101                    ;F452: 7E F1 83       '~..'
ZF455   TIM     #$08,currently_playing_bitfield               ;F455: 7B 08 B5       '{..'
        BEQ     ZF45D                    ;F458: 27 03          ''.'
        JMP     sel_card_at_101                    ;F45A: 7E F1 0B       '~..'
ZF45D   JMP     mainloop                    ;F45D: 7E F0 5A       '~.Z'
stop_track   LDAA    #$00                     ;F460: 86 00          '..'
        STAA    opn_ch                    ;F462: 97 86          '..'
        JSR     opn_keyoff                    ;F464: BD F5 D2       '...'
        INC     >opn_ch                   ;F467: 7C 00 86       '|..'
        JSR     opn_keyoff                    ;F46A: BD F5 D2       '...'
        INC     >opn_ch                   ;F46D: 7C 00 86       '|..'
        JSR     opn_keyoff                    ;F470: BD F5 D2       '...'
        LDAA    #$28                     ;F473: 86 28          '.('
        LDAB    #$27                     ;F475: C6 27          '.''
        JSR     opn_write                    ;F477: BD F4 90       '...' write timer A/B control and 3ch mode
        LDAA    #$0F                     ;F47A: 86 0F          '..' probably all off 1111
        LDAB    #$0E                     ;F47C: C6 0E          '..'
        JSR     opn_write                    ;F47E: BD F4 90       '...' io a
        AIM     #$FB,TIMERCTL               ;F481: 71 FB 08       'q..' disable TOI
        AIM     #$F7,PORT2               ;F484: 71 F7 03       'q..'
        AIM     #$FE,PORT2               ;F487: 71 FE 03       'q..'
        AIM     #$FB,PORT2               ;F48A: 71 FB 03       'q..'
        JMP     mainloop                    ;F48D: 7E F0 5A       '~.Z'
opn_write   PSHA                             ;F490: 36             '6'
        LDAA    #$80                     ;F491: 86 80          '..'
ZF493   BITA    opn_reg                    ;F493: B5 01 00       '...'
        BNE     ZF493                    ;F496: 26 FB          '&.'
        STAB    opn_reg                    ;F498: F7 01 00       '...'
ZF49B   BITA    opn_reg                    ;F49B: B5 01 00       '...'
        BNE     ZF49B                    ;F49E: 26 FB          '&.'
        TIM     #$80,PORT4               ;F4A0: 7B 80 07       '{..'
        BEQ     ZF4AA                    ;F4A3: 27 05          ''.' bra if ml301
        PULA                             ;F4A5: 32             '2'
        STAA    opn_data_ml304                    ;F4A6: B7 01 40       '..@'
        RTS                              ;F4A9: 39             '9'
ZF4AA   PULA                             ;F4AA: 32             '2'
        STAA    card_d_data                    ;F4AB: B7 01 01       '...'
        RTS                              ;F4AE: 39             '9'
opn_read   LDAA    #$80                     ;F4AF: 86 80          '..'
ZF4B1   BITA    opn_reg                    ;F4B1: B5 01 00       '...'
        BNE     ZF4B1                    ;F4B4: 26 FB          '&.'
        STAB    opn_reg                    ;F4B6: F7 01 00       '...'
ZF4B9   BITA    opn_reg                    ;F4B9: B5 01 00       '...'
        BNE     ZF4B9                    ;F4BC: 26 FB          '&.'
        TIM     #$80,PORT4               ;F4BE: 7B 80 07       '{..'
        BEQ     ZF4C7                    ;F4C1: 27 04          ''.' bra if ml301
        LDAA    opn_data_ml304                    ;F4C3: B6 01 40       '..@'
        RTS                              ;F4C6: 39             '9'
ZF4C7   LDAA    card_d_data                    ;F4C7: B6 01 01       '...'
        RTS                              ;F4CA: 39             '9'
read_tune_data   PSHX                             ;F4CB: 3C             '<'
        LDX     card_pointer                    ;F4CC: DE A9          '..'
        LDAA    ,X                       ;F4CE: A6 00          '..'
        PULX                             ;F4D0: 38             '8'
        RTS                              ;F4D1: 39             '9'
load_ch_patch   LDAB    opn_ch                    ;F4D2: D6 86          '..'
        ADDB    #$30                     ;F4D4: CB 30          '.0'
        CLRA                             ;F4D6: 4F             'O'
        STAA    patch_upload_tmp                    ;F4D7: 97 92          '..'
        LDX     patch_loc_word                    ;F4D9: DE B1          '..'
ZF4DB   STX     card_addr                    ;F4DB: FF 01 05       '...'
        JSR     read_tune_data                    ;F4DE: BD F4 CB       '...'
        JSR     opn_write                    ;F4E1: BD F4 90       '...' dt/mul
        INCB                             ;F4E4: 5C             '\'
        INCB                             ;F4E5: 5C             '\'
        INCB                             ;F4E6: 5C             '\'
        INCB                             ;F4E7: 5C             '\'
        INX                              ;F4E8: 08             '.'
        INC     >patch_upload_tmp                   ;F4E9: 7C 00 92       '|..'
        LDAA    patch_upload_tmp                    ;F4EC: 96 92          '..'
        CMPA    #$18                     ;F4EE: 81 18          '..'
        BNE     ZF4DB                    ;F4F0: 26 E9          '&.'
        LDAB    opn_ch                    ;F4F2: D6 86          '..'
        ADDB    #$B0                     ;F4F4: CB B0          '..'
        STX     card_addr                    ;F4F6: FF 01 05       '...'
        JSR     read_tune_data                    ;F4F9: BD F4 CB       '...'
        JSR     opn_write                    ;F4FC: BD F4 90       '...' write algo+fb
        LDX     patch_loc_word                    ;F4FF: DE B1          '..'
        LDAB    #$04                     ;F501: C6 04          '..'
        ABX                              ;F503: 3A             ':'
        STX     card_addr                    ;F504: FF 01 05       '...' first tl in patch (patch loc + 4)
        JSR     read_tune_data                    ;F507: BD F4 CB       '...'
        STAA    tl_op1                    ;F50A: 97 A2          '..'
        INX                              ;F50C: 08             '.'
        STX     card_addr                    ;F50D: FF 01 05       '...'
        JSR     read_tune_data                    ;F510: BD F4 CB       '...'
        STAA    tl_op3                    ;F513: 97 A4          '..'
        INX                              ;F515: 08             '.'
        STX     card_addr                    ;F516: FF 01 05       '...'
        JSR     read_tune_data                    ;F519: BD F4 CB       '...'
        STAA    tl_op2                    ;F51C: 97 A3          '..'
        INX                              ;F51E: 08             '.'
        STX     card_addr                    ;F51F: FF 01 05       '...'
        JSR     read_tune_data                    ;F522: BD F4 CB       '...'
        STAA    tl_op4                    ;F525: 97 A5          '..'
        LDX     patch_loc_word                    ;F527: DE B1          '..'
        LDAB    #$18                     ;F529: C6 18          '..'
        ABX                              ;F52B: 3A             ':'
        STX     card_addr                    ;F52C: FF 01 05       '...' fb/algo (patch loc + 0x18)
        JSR     read_tune_data                    ;F52F: BD F4 CB       '...'
        ANDA    #$07                     ;F532: 84 07          '..'
        LDX     #fb_algo_base                   ;F534: CE 00 93       '...'
        JSR     add_opn_ch_x                    ;F537: BD F7 1D       '...'
        STAA    ,X                       ;F53A: A7 00          '..' 
        LDAA    tl_op1                    ;F53C: 96 A2          '..'
        LDX     #tl_op1_base                   ;F53E: CE 00 96       '...'
        JSR     add_opn_ch_x                    ;F541: BD F7 1D       '...'
        STAA    ,X                       ;F544: A7 00          '..'
        LDAA    tl_op2                    ;F546: 96 A3          '..'
        LDX     #tl_op2_base                   ;F548: CE 00 99       '...'
        JSR     add_opn_ch_x                    ;F54B: BD F7 1D       '...'
        STAA    ,X                       ;F54E: A7 00          '..'
        LDAA    tl_op3                    ;F550: 96 A4          '..'
        LDX     #tl_op3_base                   ;F552: CE 00 9C       '...'
        JSR     add_opn_ch_x                    ;F555: BD F7 1D       '...'
        STAA    ,X                       ;F558: A7 00          '..'
        LDAA    tl_op4                    ;F55A: 96 A5          '..'
        LDX     #tl_op4_base                   ;F55C: CE 00 9F       '...'
        JSR     add_opn_ch_x                    ;F55F: BD F7 1D       '...'
        STAA    ,X                       ;F562: A7 00          '..'
        RTS                              ;F564: 39             '9'
opn_write_4op_tl   LDX     #fb_algo_base                   ;F565: CE 00 93       '...'
        JSR     add_opn_ch_x                    ;F568: BD F7 1D       '...'
        LDAA    ,X                       ;F56B: A6 00          '..'
        CMPA    #$07                     ;F56D: 81 07          '..' all of these CMPAs are to write TL only for "slot" (connected directly to output) operators
        BEQ     ZF5B5                    ;F56F: 27 44          ''D'
        CMPA    #$06                     ;F571: 81 06          '..'
        BEQ     ZF5A2                    ;F573: 27 2D          ''-'
        CMPA    #$05                     ;F575: 81 05          '..'
        BEQ     ZF5A2                    ;F577: 27 29          '')'
        CMPA    #$04                     ;F579: 81 04          '..'
        BEQ     ZF58F                    ;F57B: 27 12          ''.'
ZF57D   LDX     #tl_op4_base                   ;F57D: CE 00 9F       '...'
        JSR     add_opn_ch_x                    ;F580: BD F7 1D       '...'
        LDAA    ,X                       ;F583: A6 00          '..'
        ADDA    opn_tl_modifier                    ;F585: 9B A8          '..'
        LDAB    #$4C                     ;F587: C6 4C          '.L'
        ADDB    opn_ch                    ;F589: DB 86          '..'
        JSR     opn_write                    ;F58B: BD F4 90       '...' tl
        RTS                              ;F58E: 39             '9'
ZF58F   LDX     #tl_op2_base                   ;F58F: CE 00 99       '...'
        JSR     add_opn_ch_x                    ;F592: BD F7 1D       '...'
        LDAA    ,X                       ;F595: A6 00          '..'
        ADDA    opn_tl_modifier                    ;F597: 9B A8          '..'
        LDAB    #$48                     ;F599: C6 48          '.H'
        ADDB    opn_ch                    ;F59B: DB 86          '..'
        JSR     opn_write                    ;F59D: BD F4 90       '...' tl
        BRA     ZF57D                    ;F5A0: 20 DB          ' .'
ZF5A2   LDX     #tl_op3_base                   ;F5A2: CE 00 9C       '...'
        JSR     add_opn_ch_x                    ;F5A5: BD F7 1D       '...'
        LDAA    ,X                       ;F5A8: A6 00          '..'
        ADDA    opn_tl_modifier                    ;F5AA: 9B A8          '..'
        LDAB    #$43                     ;F5AC: C6 43          '.C' BUG!!! should be $44
        ADDB    opn_ch                    ;F5AE: DB 86          '..'
        JSR     opn_write                    ;F5B0: BD F4 90       '...' tl
        BRA     ZF58F                    ;F5B3: 20 DA          ' .'
ZF5B5   LDX     #tl_op1_base                   ;F5B5: CE 00 96       '...'
        JSR     add_opn_ch_x                    ;F5B8: BD F7 1D       '...'
        LDAA    ,X                       ;F5BB: A6 00          '..'
        ADDA    opn_tl_modifier                    ;F5BD: 9B A8          '..'
        LDAB    #$40                     ;F5BF: C6 40          '.@'
        ADDB    opn_ch                    ;F5C1: DB 86          '..'
        JSR     opn_write                    ;F5C3: BD F4 90       '...' tl
        BRA     ZF5A2                    ;F5C6: 20 DA          ' .'
opn_keyon   LDAA    opn_ch                    ;F5C8: 96 86          '..'
        ORAA    #$F0                     ;F5CA: 8A F0          '..'
        LDAB    #$28                     ;F5CC: C6 28          '.('
        JSR     opn_write                    ;F5CE: BD F4 90       '...' kon
        RTS                              ;F5D1: 39             '9'
opn_keyoff   LDAA    opn_ch                    ;F5D2: 96 86          '..'
        ANDA    #$0F                     ;F5D4: 84 0F          '..'
        LDAB    #$28                     ;F5D6: C6 28          '.('
        JSR     opn_write                    ;F5D8: BD F4 90       '...' kon
        RTS                              ;F5DB: 39             '9'
opn_write_freq   LDAB    cur_note_freq                    ;F5DC: D6 A6          '..'
        CLRA                             ;F5DE: 4F             'O'
        ASLD                             ;F5DF: 05             '.' shl a <- b
        ASLD                             ;F5E0: 05             '.'
        ASLD                             ;F5E1: 05             '.'
        ASLD                             ;F5E2: 05             '.'
        LSRB                             ;F5E3: 54             'T'
        LSRB                             ;F5E4: 54             'T'
        LSRB                             ;F5E5: 54             'T'
        STAB    unused1                    ;F5E6: D7 A7          '..'
        LDX     #scale_lut                   ;F5E8: CE F0 00       '...'
        ABX                              ;F5EB: 3A             ':' x+=b
        LDAB    ,X                       ;F5EC: E6 00          '..'
        ASLA                             ;F5EE: 48             'H'
        ASLA                             ;F5EF: 48             'H'
        ASLA                             ;F5F0: 48             'H'
        ABA                              ;F5F1: 1B             '.' a+=b
        LDAB    #$A4                     ;F5F2: C6 A4          '..'
        ADDB    opn_ch                    ;F5F4: DB 86          '..'
        JSR     opn_write                    ;F5F6: BD F4 90       '...' freq hi
        INX                              ;F5F9: 08             '.'
        LDAA    ,X                       ;F5FA: A6 00          '..'
        LDAB    #$A0                     ;F5FC: C6 A0          '..'
        ADDB    opn_ch                    ;F5FE: DB 86          '..'
        JSR     opn_write                    ;F600: BD F4 90       '...' freq lo
        RTS                              ;F603: 39             '9'
opn_timerb_setup   LDAA    #$FF                     ;F604: 86 FF          '..'
        LDAB    opn_timer_b                    ;F606: D6 8A          '..'
        SBA                              ;F608: 10             '.' a = ff - timerb
        LSRA                             ;F609: 44             'D'
        LSRA                             ;F60A: 44             'D'
        LSRA                             ;F60B: 44             'D' a /= 8
        STAA    M008B                    ;F60C: 97 8B          '..'
        LDAB    #$0F                     ;F60E: C6 0F          '..'
        JSR     opn_read                    ;F610: BD F4 AF       '...' a = io port b
        LSRA                             ;F613: 44             'D' a >>= 1
        ANDA    #$0F                     ;F614: 84 0F          '..' a &= 0xf
        CMPA    #$0A                     ;F616: 81 0A          '..'
        BGE     ZF647                    ;F618: 2C 2D          ',-' bra rts
        LDAB    opn_timer_b                    ;F61A: D6 8A          '..'
        CMPA    #$05                     ;F61C: 81 05          '..'
        BEQ     ZF640                    ;F61E: 27 20          '' ' bra use normal value
        BMI     ZF631                    ;F620: 2B 0F          '+.'
ZF622   CLC                              ;F622: 0C             '.'
        ADDB    M008B                    ;F623: DB 8B          '..'
        BCC     ZF629                    ;F625: 24 02          '$.'
        LDAB    #$FF                     ;F627: C6 FF          '..'
ZF629   DECA                             ;F629: 4A             'J'
        CMPA    #$05                     ;F62A: 81 05          '..'
        BNE     ZF622                    ;F62C: 26 F4          '&.'
        TBA                              ;F62E: 17             '.'
        BRA     ZF642                    ;F62F: 20 11          ' .' bra write A
ZF631   CLC                              ;F631: 0C             '.'
        SBCB    M008B                    ;F632: D2 8B          '..'
        BCC     ZF638                    ;F634: 24 02          '$.'
        LDAB    #$00                     ;F636: C6 00          '..'
ZF638   INCA                             ;F638: 4C             'L'
        CMPA    #$05                     ;F639: 81 05          '..'
        BNE     ZF631                    ;F63B: 26 F4          '&.'
        TBA                              ;F63D: 17             '.'
        BRA     ZF642                    ;F63E: 20 02          ' .' bra write A
ZF640   LDAA    opn_timer_b                    ;F640: 96 8A          '..' use normal value
ZF642   LDAB    #$26                     ;F642: C6 26          '.&' write A
        JSR     opn_write                    ;F644: BD F4 90       '...' timer b
ZF647   RTS                              ;F647: 39             '9'
ml304_setup_next_note_trk1   LDX     track1_loc_word                    ;F648: DE 80          '..'
        STX     card_addr                    ;F64A: FF 01 05       '...'
        JSR     read_tune_data                    ;F64D: BD F4 CB       '...'
        CMPA    #$FE                     ;F650: 81 FE          '..'
        BEQ     ZF686                    ;F652: 27 32          ''2'
        CMPA    #$FF                     ;F654: 81 FF          '..'
        BEQ     ZF68B                    ;F656: 27 33          ''3'
        STAA    cur_note_freq                    ;F658: 97 A6          '..'
        INX                              ;F65A: 08             '.'
        STX     card_addr                    ;F65B: FF 01 05       '...'
        JSR     read_tune_data                    ;F65E: BD F4 CB       '...'
        STAA    track1_note_len                    ;F661: 97 8C          '..'
        INX                              ;F663: 08             '.'
        STX     card_addr                    ;F664: FF 01 05       '...'
        JSR     read_tune_data                    ;F667: BD F4 CB       '...'
        STAA    track1_kon_len                    ;F66A: 97 8F          '..'
        INX                              ;F66C: 08             '.'
        STX     card_addr                    ;F66D: FF 01 05       '...'
        JSR     read_tune_data                    ;F670: BD F4 CB       '...'
        STAA    opn_tl_modifier                    ;F673: 97 A8          '..'
        INX                              ;F675: 08             '.'
        STX     track1_loc_word                    ;F676: DF 80          '..'
        LDAA    track1_kon_len                    ;F678: 96 8F          '..'
        BEQ     ZF685                    ;F67A: 27 09          ''.'
        JSR     opn_write_4op_tl                    ;F67C: BD F5 65       '..e'
        JSR     opn_write_freq                    ;F67F: BD F5 DC       '...'
        JSR     opn_keyon                    ;F682: BD F5 C8       '...'
ZF685   RTS                              ;F685: 39             '9'
ZF686   LDAA    #$FF                     ;F686: 86 FF          '..'
        STAA    track1_is_finished                    ;F688: 97 87          '..'
        RTS                              ;F68A: 39             '9'
ZF68B   OIM     #$01,tune_found_ff_flag               ;F68B: 72 01 B9       'r..'
        RTS                              ;F68E: 39             '9'
ml304_setup_next_note_trk2   LDX     track2_loc_word                    ;F68F: DE 82          '..'
        STX     card_addr                    ;F691: FF 01 05       '...'
        JSR     read_tune_data                    ;F694: BD F4 CB       '...'
        CMPA    #$FE                     ;F697: 81 FE          '..'
        BEQ     ZF6CD                    ;F699: 27 32          ''2'
        STAA    cur_note_freq                    ;F69B: 97 A6          '..'
        CMPA    #$FF                     ;F69D: 81 FF          '..'
        BEQ     ZF6D2                    ;F69F: 27 31          ''1'
        INX                              ;F6A1: 08             '.'
        STX     card_addr                    ;F6A2: FF 01 05       '...'
        JSR     read_tune_data                    ;F6A5: BD F4 CB       '...'
        STAA    track2_note_len                    ;F6A8: 97 8D          '..'
        INX                              ;F6AA: 08             '.'
        STX     card_addr                    ;F6AB: FF 01 05       '...'
        JSR     read_tune_data                    ;F6AE: BD F4 CB       '...'
        STAA    track2_kon_len                    ;F6B1: 97 90          '..'
        INX                              ;F6B3: 08             '.'
        STX     card_addr                    ;F6B4: FF 01 05       '...'
        JSR     read_tune_data                    ;F6B7: BD F4 CB       '...'
        STAA    opn_tl_modifier                    ;F6BA: 97 A8          '..'
        INX                              ;F6BC: 08             '.'
        STX     track2_loc_word                    ;F6BD: DF 82          '..'
        LDAA    track2_kon_len                    ;F6BF: 96 90          '..'
        BEQ     ZF6CC                    ;F6C1: 27 09          ''.'
        JSR     opn_write_4op_tl                    ;F6C3: BD F5 65       '..e'
        JSR     opn_write_freq                    ;F6C6: BD F5 DC       '...'
        JSR     opn_keyon                    ;F6C9: BD F5 C8       '...'
ZF6CC   RTS                              ;F6CC: 39             '9'
ZF6CD   LDAA    #$FF                     ;F6CD: 86 FF          '..'
        STAA    track2_is_finished                    ;F6CF: 97 88          '..'
        RTS                              ;F6D1: 39             '9'
ZF6D2   OIM     #$01,tune_found_ff_flag               ;F6D2: 72 01 B9       'r..'
        RTS                              ;F6D5: 39             '9'
ml304_setup_next_note_trk3   LDX     track3_loc_word                    ;F6D6: DE 84          '..'
        STX     card_addr                    ;F6D8: FF 01 05       '...'
        JSR     read_tune_data                    ;F6DB: BD F4 CB       '...'
        CMPA    #$FE                     ;F6DE: 81 FE          '..'
        BEQ     ZF714                    ;F6E0: 27 32          ''2'
        CMPA    #$FF                     ;F6E2: 81 FF          '..'
        BEQ     ZF719                    ;F6E4: 27 33          ''3'
        STAA    cur_note_freq                    ;F6E6: 97 A6          '..'
        INX                              ;F6E8: 08             '.'
        STX     card_addr                    ;F6E9: FF 01 05       '...'
        JSR     read_tune_data                    ;F6EC: BD F4 CB       '...'
        STAA    track3_note_len                    ;F6EF: 97 8E          '..'
        INX                              ;F6F1: 08             '.'
        STX     card_addr                    ;F6F2: FF 01 05       '...'
        JSR     read_tune_data                    ;F6F5: BD F4 CB       '...'
        STAA    track3_kon_len                    ;F6F8: 97 91          '..'
        INX                              ;F6FA: 08             '.'
        STX     card_addr                    ;F6FB: FF 01 05       '...'
        JSR     read_tune_data                    ;F6FE: BD F4 CB       '...'
        STAA    opn_tl_modifier                    ;F701: 97 A8          '..'
        INX                              ;F703: 08             '.'
        STX     track3_loc_word                    ;F704: DF 84          '..'
        LDAA    track3_kon_len                    ;F706: 96 91          '..'
        BEQ     ZF713                    ;F708: 27 09          ''.'
        JSR     opn_write_4op_tl                    ;F70A: BD F5 65       '..e'
        JSR     opn_write_freq                    ;F70D: BD F5 DC       '...'
        JSR     opn_keyon                    ;F710: BD F5 C8       '...'
ZF713   RTS                              ;F713: 39             '9'
ZF714   LDAA    #$FF                     ;F714: 86 FF          '..'
        STAA    track3_is_finished                    ;F716: 97 89          '..'
        RTS                              ;F718: 39             '9'
ZF719   OIM     #$01,tune_found_ff_flag               ;F719: 72 01 B9       'r..'
        RTS                              ;F71C: 39             '9'
add_opn_ch_x   LDAB    opn_ch                    ;F71D: D6 86          '..'
        CMPB    #$00                     ;F71F: C1 00          '..'
        BEQ     ZF729                    ;F721: 27 06          ''.'
        INX                              ;F723: 08             '.'
        CMPB    #$01                     ;F724: C1 01          '..'
        BEQ     ZF729                    ;F726: 27 01          ''.'
        INX                              ;F728: 08             '.'
ZF729   RTS                              ;F729: 39             '9'
spin_delay_100ms   PSHA                             ;F72A: 36             '6'
        CLRB                             ;F72B: 5F             '_'
ZF72C   CLRA                             ;F72C: 4F             'O'
ZF72D   INCA                             ;F72D: 4C             'L'
        BNE     ZF72D                    ;F72E: 26 FD          '&.'
        INCB                             ;F730: 5C             '\'
        CMPB    #$64                     ;F731: C1 64          '.d'
        BNE     ZF72C                    ;F733: 26 F7          '&.'
        PULA                             ;F735: 32             '2'
        RTS                              ;F736: 39             '9'
hdlr_IRQ AIM     #$FE,int_flag               ;F737: 71 FE B3       'q..'
        LDAA    #$2A                     ;F73A: 86 2A          '.*'
        LDAB    #$27                     ;F73C: C6 27          '.''
        JSR     opn_write                    ;F73E: BD F4 90       '...' clear timer b flag
        TIM     #$80,PORT4               ;F741: 7B 80 07       '{..'
        BEQ     ZF775                    ;F744: 27 2F          ''/' bra if ml301
        JSR     opn_timerb_setup                    ;F746: BD F6 04       '...'
ZF749   LDAA    track1_kon_len                    ;F749: 96 8F          '..'
        BEQ     ZF750                    ;F74B: 27 03          ''.'
        DECA                             ;F74D: 4A             'J'
        STAA    track1_kon_len                    ;F74E: 97 8F          '..'
ZF750   LDAA    track1_note_len                    ;F750: 96 8C          '..'
        BEQ     ZF757                    ;F752: 27 03          ''.'
        DECA                             ;F754: 4A             'J'
        STAA    track1_note_len                    ;F755: 97 8C          '..'
ZF757   LDAA    track2_kon_len                    ;F757: 96 90          '..'
        BEQ     ZF75E                    ;F759: 27 03          ''.'
        DECA                             ;F75B: 4A             'J'
        STAA    track2_kon_len                    ;F75C: 97 90          '..'
ZF75E   LDAA    track2_note_len                    ;F75E: 96 8D          '..'
        BEQ     ZF765                    ;F760: 27 03          ''.'
        DECA                             ;F762: 4A             'J'
        STAA    track2_note_len                    ;F763: 97 8D          '..'
ZF765   LDAA    track3_kon_len                    ;F765: 96 91          '..'
        BEQ     ZF76C                    ;F767: 27 03          ''.'
        DECA                             ;F769: 4A             'J'
        STAA    track3_kon_len                    ;F76A: 97 91          '..'
ZF76C   LDAA    track3_note_len                    ;F76C: 96 8E          '..'
        BEQ     ZF773                    ;F76E: 27 03          ''.'
        DECA                             ;F770: 4A             'J'
        STAA    track3_note_len                    ;F771: 97 8E          '..'
ZF773   CLI                              ;F773: 0E             '.'
        RTI                              ;F774: 3B             ';'
ZF775   JSR     ZFAE5                    ;F775: BD FA E5       '...'
        JMP     ZF749                    ;F778: 7E F7 49       '~.I'
hdlr_SWI3 TIM     #$80,PORT4               ;F77B: 7B 80 07       '{..'
        BNE     ZF783                    ;F77E: 26 03          '&.' bra if ml304
        JMP     ml301_swi_isr                    ;F780: 7E FB BB       '~..'
ZF783   PSHA                             ;F783: 36             '6'
        PSHB                             ;F784: 37             '7'
        PSHX                             ;F785: 3C             '<'
        LDAA    PORT1                    ;F786: 96 02          '..'
        COMA                             ;F788: 43             'C'
        STAA    port1_isr_tmp                    ;F789: 97 B7          '..'
        BEQ     isr_swi3_nothing_pressed                    ;F78B: 27 3C          ''<' bra if nothing pressed
        TIM     #$01,nothing_pressed_in_isr               ;F78D: 7B 01 B8       '{..'
        BEQ     isr_swi3_exit                    ;F790: 27 2E          ''.'
        EORA    pressed_switch_bitfield                    ;F792: 98 B6          '..'
        ANDA    port1_isr_tmp                    ;F794: 94 B7          '..'
        STAA    port1_isr_tmp                    ;F796: 97 B7          '..'
        TIM     #$80,port1_isr_tmp               ;F798: 7B 80 B7       '{..'
        BNE     ZF7DA                    ;F79B: 26 3D          '&='
        TIM     #$01,port1_isr_tmp               ;F79D: 7B 01 B7       '{..'
        BNE     ZF7CF                    ;F7A0: 26 2D          '&-'
        TIM     #$40,port1_isr_tmp               ;F7A2: 7B 40 B7       '{@.'
        BNE     ZF7F0                    ;F7A5: 26 49          '&I'
        TIM     #$02,port1_isr_tmp               ;F7A7: 7B 02 B7       '{..'
        BNE     ZF7E5                    ;F7AA: 26 39          '&9'
        TIM     #$20,port1_isr_tmp               ;F7AC: 7B 20 B7       '{ .'
        BNE     ZF806                    ;F7AF: 26 55          '&U'
        TIM     #$04,port1_isr_tmp               ;F7B1: 7B 04 B7       '{..'
        BNE     ZF7FB                    ;F7B4: 26 45          '&E'
        TIM     #$10,port1_isr_tmp               ;F7B6: 7B 10 B7       '{..'
        BNE     ZF81C                    ;F7B9: 26 61          '&a'
        TIM     #$08,port1_isr_tmp               ;F7BB: 7B 08 B7       '{..'
        BNE     ZF811                    ;F7BE: 26 51          '&Q'
isr_swi3_exit   LDAA    TIMERCTL                    ;F7C0: 96 08          '..' clear TOF
        LDAA    TIMERCNTHI                    ;F7C2: 96 09          '..' clear TOF
        PULX                             ;F7C4: 38             '8'
        PULB                             ;F7C5: 33             '3'
        PULA                             ;F7C6: 32             '2'
        CLI                              ;F7C7: 0E             '.'
        RTI                              ;F7C8: 3B             ';'
isr_swi3_nothing_pressed   OIM     #$01,nothing_pressed_in_isr               ;F7C9: 72 01 B8       'r..' 
        JMP     isr_swi3_exit                    ;F7CC: 7E F7 C0       '~..'
ZF7CF   TIM     #$01,currently_playing_bitfield               ;F7CF: 7B 01 B5       '{..'
        BNE     ZF827                    ;F7D2: 26 53          '&S'
        OIM     #$01,currently_playing_bitfield               ;F7D4: 72 01 B5       'r..'
        JMP     isr_swi3_exit                    ;F7D7: 7E F7 C0       '~..'
ZF7DA   TIM     #$80,currently_playing_bitfield               ;F7DA: 7B 80 B5       '{..'
        BNE     ZF827                    ;F7DD: 26 48          '&H'
        OIM     #$80,currently_playing_bitfield               ;F7DF: 72 80 B5       'r..'
        JMP     isr_swi3_exit                    ;F7E2: 7E F7 C0       '~..'
ZF7E5   TIM     #$02,currently_playing_bitfield               ;F7E5: 7B 02 B5       '{..'
        BNE     ZF827                    ;F7E8: 26 3D          '&='
        OIM     #$02,currently_playing_bitfield               ;F7EA: 72 02 B5       'r..'
        JMP     isr_swi3_exit                    ;F7ED: 7E F7 C0       '~..'
ZF7F0   TIM     #$40,currently_playing_bitfield               ;F7F0: 7B 40 B5       '{@.'
        BNE     ZF827                    ;F7F3: 26 32          '&2'
        OIM     #$40,currently_playing_bitfield               ;F7F5: 72 40 B5       'r@.'
        JMP     isr_swi3_exit                    ;F7F8: 7E F7 C0       '~..'
ZF7FB   TIM     #$04,currently_playing_bitfield               ;F7FB: 7B 04 B5       '{..'
        BNE     ZF827                    ;F7FE: 26 27          '&''
        OIM     #$04,currently_playing_bitfield               ;F800: 72 04 B5       'r..'
        JMP     isr_swi3_exit                    ;F803: 7E F7 C0       '~..'
ZF806   TIM     #$20,currently_playing_bitfield               ;F806: 7B 20 B5       '{ .'
        BNE     ZF827                    ;F809: 26 1C          '&.'
        OIM     #$20,currently_playing_bitfield               ;F80B: 72 20 B5       'r .'
        JMP     isr_swi3_exit                    ;F80E: 7E F7 C0       '~..'
ZF811   TIM     #$08,currently_playing_bitfield               ;F811: 7B 08 B5       '{..'
        BNE     ZF827                    ;F814: 26 11          '&.'
        OIM     #$08,currently_playing_bitfield               ;F816: 72 08 B5       'r..'
        JMP     isr_swi3_exit                    ;F819: 7E F7 C0       '~..'
ZF81C   TIM     #$10,currently_playing_bitfield               ;F81C: 7B 10 B5       '{..'
        BNE     ZF827                    ;F81F: 26 06          '&.'
        OIM     #$10,currently_playing_bitfield               ;F821: 72 10 B5       'r..'
        JMP     isr_swi3_exit                    ;F824: 7E F7 C0       '~..'
ZF827   OIM     #$01,already_playing               ;F827: 72 01 B4       'r..' all bra here if selected card is already playing?
        AIM     #$FE,nothing_pressed_in_isr               ;F82A: 71 FE B8       'q..'
        JMP     isr_swi3_exit                    ;F82D: 7E F7 C0       '~..'
ml301_mode   CLRA                             ;F830: 4F             'O'
        STAA    PORT1                    ;F831: 97 02          '..'
        STAA    PORT2                    ;F833: 97 03          '..'
        LDAA    #$70                     ;F835: 86 70          '.p'
        STAA    DDR1                    ;F837: 97 00          '..'
        LDAA    #$08                     ;F839: 86 08          '..'
        STAA    DDR2                    ;F83B: 97 01          '..'
        LDAA    #$7F                     ;F83D: 86 7F          '..'
        STAA    DDR4                    ;F83F: 97 05          '..'
        LDS     #M00FF                   ;F841: 8E 00 FF       '...'
        LDAB    #$2D                     ;F844: C6 2D          '.-'
        JSR     opn_write                    ;F846: BD F4 90       '...' prescaler
        LDAB    #$07                     ;F849: C6 07          '..'
        LDAA    #$7F                     ;F84B: 86 7F          '..'
        JSR     opn_write                    ;F84D: BD F4 90       '...' ssg enable
        LDAA    #$03                     ;F850: 86 03          '..' 0011
        LDAB    #$0E                     ;F852: C6 0E          '..'
        JSR     opn_write                    ;F854: BD F4 90       '...' io a
        CLRA                             ;F857: 4F             'O'
        STAA    opn_ch                    ;F858: 97 86          '..'
        JSR     opn_keyoff                    ;F85A: BD F5 D2       '...'
        INC     >opn_ch                   ;F85D: 7C 00 86       '|..'
        JSR     opn_keyoff                    ;F860: BD F5 D2       '...'
        INC     >opn_ch                   ;F863: 7C 00 86       '|..'
        JSR     opn_keyoff                    ;F866: BD F5 D2       '...'
ZF869   CLRA                             ;F869: 4F             'O'
        STAA    track1_note_len                    ;F86A: 97 8C          '..'
        STAA    track2_note_len                    ;F86C: 97 8D          '..'
        STAA    track3_note_len                    ;F86E: 97 8E          '..'
        STAA    track1_kon_len                    ;F870: 97 8F          '..'
        STAA    track2_kon_len                    ;F872: 97 90          '..'
        STAA    track3_kon_len                    ;F874: 97 91          '..'
        STAA    unk_M00BE                    ;F876: 97 BE          '..'
        STAA    M00C1                    ;F878: 97 C1          '..'
        STAA    M00BF                    ;F87A: 97 BF          '..'
        STAA    M00C0                    ;F87C: 97 C0          '..'
        STAA    already_playing                    ;F87E: 97 B4          '..'
        STAA    int_flag                    ;F880: 97 B3          '..'
        TIM     #$02,PORT1               ;F882: 7B 02 02       '{..'
        BNE     ZF88A                    ;F885: 26 03          '&.'
        JMP     ZF92F                    ;F887: 7E F9 2F       '~./'
ZF88A   TIM     #$08,PORT1               ;F88A: 7B 08 02       '{..'
        BNE     ZF892                    ;F88D: 26 03          '&.'
        JMP     ZF962                    ;F88F: 7E F9 62       '~.b'
ZF892   TIM     #$80,PORT1               ;F892: 7B 80 02       '{..'
        BEQ     ZF89A                    ;F895: 27 03          ''.'
        JMP     ZF96C                    ;F897: 7E F9 6C       '~.l'
ZF89A   TIM     #$01,PORT1               ;F89A: 7B 01 02       '{..'
        BEQ     ZF8A2                    ;F89D: 27 03          ''.'
        JMP     ZF869                    ;F89F: 7E F8 69       '~.i'
ZF8A2   JSR     spin_delay_100ms                    ;F8A2: BD F7 2A       '..*'
        TIM     #$01,PORT1               ;F8A5: 7B 01 02       '{..'
        BNE     ZF869                    ;F8A8: 26 BF          '&.'
        INC     >unk_M00BE                   ;F8AA: 7C 00 BE       '|..'
        OIM     #$10,PORT1               ;F8AD: 72 10 02       'r..'
        LDAA    #$01                     ;F8B0: 86 01          '..'
        LDAB    #$0E                     ;F8B2: C6 0E          '..'
        JSR     opn_write                    ;F8B4: BD F4 90       '...' io a
        LDX     built_in_tune_1                    ;F8B7: FE FD 00       '...'
        STX     unk_M00BC                    ;F8BA: DF BC          '..'
ZF8BC   LDX     #MFFFF                   ;F8BC: CE FF FF       '...'
        STX     TIMERCNTHI                    ;F8BF: DF 09          '..'
        OIM     #$04,TIMERCTL               ;F8C1: 72 04 08       'r..' enable TOI
        CLI                              ;F8C4: 0E             '.'
        LDX     unk_M00BC                    ;F8C5: DE BC          '..'
        LDD     $06,X                    ;F8C7: EC 06          '..'
        BEQ     ZF91A                    ;F8C9: 27 4F          ''O'
        STD     track1_loc_word                    ;F8CB: DD 80          '..'
        LDAA    #$00                     ;F8CD: 86 00          '..'
        STAA    opn_ch                    ;F8CF: 97 86          '..'
        LDX     ,X                       ;F8D1: EE 00          '..'
        JSR     ZFA79                    ;F8D3: BD FA 79       '..y'
        CLRA                             ;F8D6: 4F             'O'
        STAA    track1_is_finished                    ;F8D7: 97 87          '..'
ZF8D9   LDX     unk_M00BC                    ;F8D9: DE BC          '..'
        LDD     $08,X                    ;F8DB: EC 08          '..'
        BEQ     ZF921                    ;F8DD: 27 42          ''B'
        STD     track2_loc_word                    ;F8DF: DD 82          '..'
        INX                              ;F8E1: 08             '.'
        INX                              ;F8E2: 08             '.'
        LDAA    #$01                     ;F8E3: 86 01          '..'
        STAA    opn_ch                    ;F8E5: 97 86          '..'
        LDX     ,X                       ;F8E7: EE 00          '..'
        JSR     ZFA79                    ;F8E9: BD FA 79       '..y'
        CLRA                             ;F8EC: 4F             'O'
        STAA    track2_is_finished                    ;F8ED: 97 88          '..'
ZF8EF   LDX     unk_M00BC                    ;F8EF: DE BC          '..'
        LDD     $0A,X                    ;F8F1: EC 0A          '..'
        BEQ     ZF928                    ;F8F3: 27 33          ''3'
        STD     track3_loc_word                    ;F8F5: DD 84          '..'
        INX                              ;F8F7: 08             '.'
        INX                              ;F8F8: 08             '.'
        INX                              ;F8F9: 08             '.'
        INX                              ;F8FA: 08             '.'
        LDAA    #$02                     ;F8FB: 86 02          '..'
        STAA    opn_ch                    ;F8FD: 97 86          '..'
        LDX     ,X                       ;F8FF: EE 00          '..'
        JSR     ZFA79                    ;F901: BD FA 79       '..y'
        CLRA                             ;F904: 4F             'O'
        STAA    track3_is_finished                    ;F905: 97 89          '..'
ZF907   LDX     unk_M00BC                    ;F907: DE BC          '..'
        LDAA    $0D,X                    ;F909: A6 0D          '..'
        STAA    opn_timer_b                    ;F90B: 97 8A          '..'
        JSR     ZFAE5                    ;F90D: BD FA E5       '...'
        LDAA    #$2A                     ;F910: 86 2A          '.*'
        LDAB    #$27                     ;F912: C6 27          '.''
        JSR     opn_write                    ;F914: BD F4 90       '...'
        JMP     ZF98D                    ;F917: 7E F9 8D       '~..'
ZF91A   LDAA    #$FF                     ;F91A: 86 FF          '..'
        STAA    track1_is_finished                    ;F91C: 97 87          '..'
        JMP     ZF8D9                    ;F91E: 7E F8 D9       '~..'
ZF921   LDAA    #$FF                     ;F921: 86 FF          '..'
        STAA    track2_is_finished                    ;F923: 97 88          '..'
        JMP     ZF8EF                    ;F925: 7E F8 EF       '~..'
ZF928   LDAA    #$FF                     ;F928: 86 FF          '..'
        STAA    track3_is_finished                    ;F92A: 97 89          '..'
        JMP     ZF907                    ;F92C: 7E F9 07       '~..'
ZF92F   JSR     spin_delay_100ms                    ;F92F: BD F7 2A       '..*'
        TIM     #$02,PORT1               ;F932: 7B 02 02       '{..'
        BNE     ZF95C                    ;F935: 26 25          '&%'
ZF937   AIM     #$EF,PORT1               ;F937: 71 EF 02       'q..'
        OIM     #$08,PORT2               ;F93A: 72 08 03       'r..'
        LDAA    #$02                     ;F93D: 86 02          '..'
        LDAB    #$0E                     ;F93F: C6 0E          '..'
        JSR     opn_write                    ;F941: BD F4 90       '...' io a
        INC     >M00C1                   ;F944: 7C 00 C1       '|..'
        LDAB    #$0F                     ;F947: C6 0F          '..' io b
        JSR     opn_read                    ;F949: BD F4 AF       '...'
        BITA    #$20                     ;F94C: 85 20          '. '
        BEQ     ZF982                    ;F94E: 27 32          ''2'
        BITA    #$40                     ;F950: 85 40          '.@'
        BEQ     ZF977                    ;F952: 27 23          ''#'
ZF954   LDX     built_in_tune_1_plus2                    ;F954: FE FD 02       '...'
        STX     unk_M00BC                    ;F957: DF BC          '..'
        JMP     ZF8BC                    ;F959: 7E F8 BC       '~..'
ZF95C   AIM     #$F7,PORT2               ;F95C: 71 F7 03       'q..'
        JMP     ZF869                    ;F95F: 7E F8 69       '~.i'
ZF962   JSR     spin_delay_100ms                    ;F962: BD F7 2A       '..*'
        TIM     #$08,PORT1               ;F965: 7B 08 02       '{..'
        BNE     ZF95C                    ;F968: 26 F2          '&.'
        BRA     ZF937                    ;F96A: 20 CB          ' .'
ZF96C   JSR     spin_delay_100ms                    ;F96C: BD F7 2A       '..*'
        TIM     #$80,PORT1               ;F96F: 7B 80 02       '{..'
        BEQ     ZF95C                    ;F972: 27 E8          ''.'
        JMP     ZF937                    ;F974: 7E F9 37       '~.7'
ZF977   LDX     #$0014                   ;F977: CE 00 14       '...' 2 sec delay
ZF97A   JSR     spin_delay_100ms                    ;F97A: BD F7 2A       '..*'
        DEX                              ;F97D: 09             '.'
        BNE     ZF97A                    ;F97E: 26 FA          '&.'
        BRA     ZF954                    ;F980: 20 D2          ' .'
ZF982   LDX     #$0028                   ;F982: CE 00 28       '..(' 4 sec delay
ZF985   JSR     spin_delay_100ms                    ;F985: BD F7 2A       '..*'
        DEX                              ;F988: 09             '.'
        BNE     ZF985                    ;F989: 26 FA          '&.'
        BRA     ZF954                    ;F98B: 20 C7          ' .'
ZF98D   OIM     #$01,int_flag               ;F98D: 72 01 B3       'r..'
        WAI                              ;F990: 3E             '>'
        TIM     #$01,int_flag               ;F991: 7B 01 B3       '{..'
        BNE     ZF98D                    ;F994: 26 F7          '&.'
        LDAA    already_playing                    ;F996: 96 B4          '..'
        BEQ     ZF99D                    ;F998: 27 03          ''.'
        JMP     ZFA30                    ;F99A: 7E FA 30       '~.0'
ZF99D   LDAA    #$00                     ;F99D: 86 00          '..'
        STAA    opn_ch                    ;F99F: 97 86          '..'
        LDAA    track1_note_len                    ;F9A1: 96 8C          '..'
        BNE     ZF9AC                    ;F9A3: 26 07          '&.'
        LDAA    track1_is_finished                    ;F9A5: 96 87          '..'
        BNE     ZF9B3                    ;F9A7: 26 0A          '&.'
        JSR     ml301_setup_next_note_trk1                    ;F9A9: BD FB 2E       '...'
ZF9AC   LDAA    track1_kon_len                    ;F9AC: 96 8F          '..'
        BNE     ZF9B3                    ;F9AE: 26 03          '&.'
        JSR     opn_keyoff                    ;F9B0: BD F5 D2       '...'
ZF9B3   LDAA    #$01                     ;F9B3: 86 01          '..'
        STAA    opn_ch                    ;F9B5: 97 86          '..'
        LDAA    track2_note_len                    ;F9B7: 96 8D          '..'
        BNE     ZF9C2                    ;F9B9: 26 07          '&.'
        LDAA    track2_is_finished                    ;F9BB: 96 88          '..'
        BNE     ZF9C9                    ;F9BD: 26 0A          '&.'
        JSR     ml301_setup_next_note_trk2                    ;F9BF: BD FB 5D       '..]'
ZF9C2   LDAA    track2_kon_len                    ;F9C2: 96 90          '..'
        BNE     ZF9C9                    ;F9C4: 26 03          '&.'
        JSR     opn_keyoff                    ;F9C6: BD F5 D2       '...'
ZF9C9   LDAA    #$02                     ;F9C9: 86 02          '..'
        STAA    opn_ch                    ;F9CB: 97 86          '..'
        LDAA    track3_note_len                    ;F9CD: 96 8E          '..'
        BNE     ZF9D8                    ;F9CF: 26 07          '&.'
        LDAA    track3_is_finished                    ;F9D1: 96 89          '..'
        BNE     ZF9DF                    ;F9D3: 26 0A          '&.'
        JSR     ml301_setup_next_note_trk3                    ;F9D5: BD FB 8C       '...'
ZF9D8   LDAA    track3_kon_len                    ;F9D8: 96 91          '..'
        BNE     ZF9DF                    ;F9DA: 26 03          '&.'
        JSR     opn_keyoff                    ;F9DC: BD F5 D2       '...'
ZF9DF   LDAA    track1_is_finished                    ;F9DF: 96 87          '..'
        BEQ     ZF98D                    ;F9E1: 27 AA          ''.'
        LDAA    track2_is_finished                    ;F9E3: 96 88          '..'
        BEQ     ZF98D                    ;F9E5: 27 A6          ''.'
        LDAA    track3_is_finished                    ;F9E7: 96 89          '..'
        BEQ     ZF98D                    ;F9E9: 27 A2          ''.'
        LDAA    #$28                     ;F9EB: 86 28          '.('
        LDAB    #$27                     ;F9ED: C6 27          '.''
        JSR     opn_write                    ;F9EF: BD F4 90       '...' timer ab ctl 3ch mode
        LDAA    unk_M00BE                    ;F9F2: 96 BE          '..'
        BNE     ZFA1C                    ;F9F4: 26 26          '&&'
        LDX     #$0064                   ;F9F6: CE 00 64       '..d'
ZF9F9   JSR     spin_delay_100ms                    ;F9F9: BD F7 2A       '..*'
        DEX                              ;F9FC: 09             '.'
        BNE     ZF9F9                    ;F9FD: 26 FA          '&.'
ZF9FF   TIM     #$02,PORT1               ;F9FF: 7B 02 02       '{..'
        BEQ     ZFA0C                    ;FA02: 27 08          ''.'
        TIM     #$08,PORT1               ;FA04: 7B 08 02       '{..'
        BEQ     ZFA0C                    ;FA07: 27 03          ''.'
        AIM     #$F7,PORT2               ;FA09: 71 F7 03       'q..'
ZFA0C   AIM     #$EF,PORT1               ;FA0C: 71 EF 02       'q..'
        LDAA    #$03                     ;FA0F: 86 03          '..'
        LDAB    #$0E                     ;FA11: C6 0E          '..'
        JSR     opn_write                    ;FA13: BD F4 90       '...' io a
        AIM     #$FB,TIMERCTL               ;FA16: 71 FB 08       'q..' disable TOI
        JMP     ZF869                    ;FA19: 7E F8 69       '~.i'
ZFA1C   LDX     #$000a                   ;FA1C: CE 00 0A       '...'
ZFA1F   TIM     #$01,already_playing               ;FA1F: 7B 01 B4       '{..'
        BEQ     ZFA27                    ;FA22: 27 03          ''.'
        JMP     ZFA30                    ;FA24: 7E FA 30       '~.0'
ZFA27   JSR     spin_delay_100ms                    ;FA27: BD F7 2A       '..*'
        DEX                              ;FA2A: 09             '.'
        BNE     ZFA1F                    ;FA2B: 26 F2          '&.'
        JMP     ZF9FF                    ;FA2D: 7E F9 FF       '~..'
ZFA30   LDAA    #$00                     ;FA30: 86 00          '..'
        STAA    opn_ch                    ;FA32: 97 86          '..'
        JSR     opn_keyoff                    ;FA34: BD F5 D2       '...'
        INC     >opn_ch                   ;FA37: 7C 00 86       '|..'
        JSR     opn_keyoff                    ;FA3A: BD F5 D2       '...'
        INC     >opn_ch                   ;FA3D: 7C 00 86       '|..'
        JSR     opn_keyoff                    ;FA40: BD F5 D2       '...'
        LDAA    #$28                     ;FA43: 86 28          '.('
        LDAB    #$27                     ;FA45: C6 27          '.''
        JSR     opn_write                    ;FA47: BD F4 90       '...' timer ab ctl 3ch mode
        LDX     #$0005                   ;FA4A: CE 00 05       '...'
ZFA4D   JSR     spin_delay_100ms                    ;FA4D: BD F7 2A       '..*'
        DEX                              ;FA50: 09             '.'
        BNE     ZFA4D                    ;FA51: 26 FA          '&.'
        LDAA    #$03                     ;FA53: 86 03          '..'
        LDAB    #$0E                     ;FA55: C6 0E          '..'
        JSR     opn_write                    ;FA57: BD F4 90       '...' io a
        AIM     #$FB,TIMERCTL               ;FA5A: 71 FB 08       'q..' disable TOI
        CLRA                             ;FA5D: 4F             'O'
        STAA    track1_note_len                    ;FA5E: 97 8C          '..'
        STAA    track2_note_len                    ;FA60: 97 8D          '..'
        STAA    track3_note_len                    ;FA62: 97 8E          '..'
        STAA    track1_kon_len                    ;FA64: 97 8F          '..'
        STAA    track2_kon_len                    ;FA66: 97 90          '..'
        STAA    track3_kon_len                    ;FA68: 97 91          '..'
        STAA    unk_M00BE                    ;FA6A: 97 BE          '..'
        STAA    M00C1                    ;FA6C: 97 C1          '..'
        STAA    M00BF                    ;FA6E: 97 BF          '..'
        STAA    M00C0                    ;FA70: 97 C0          '..'
        STAA    already_playing                    ;FA72: 97 B4          '..'
        STAA    int_flag                    ;FA74: 97 B3          '..'
        JMP     ZF937                    ;FA76: 7E F9 37       '~.7'
ZFA79   LDAB    opn_ch                    ;FA79: D6 86          '..'
        ADDB    #$30                     ;FA7B: CB 30          '.0'
        CLRA                             ;FA7D: 4F             'O'
        STAA    patch_upload_tmp                    ;FA7E: 97 92          '..'
        STX     unk_M00BA                    ;FA80: DF BA          '..'
ZFA82   LDAA    ,X                       ;FA82: A6 00          '..'
        JSR     opn_write                    ;FA84: BD F4 90       '...' dt/mul
        INCB                             ;FA87: 5C             '\'
        INCB                             ;FA88: 5C             '\'
        INCB                             ;FA89: 5C             '\'
        INCB                             ;FA8A: 5C             '\'
        INX                              ;FA8B: 08             '.'
        INC     >patch_upload_tmp                   ;FA8C: 7C 00 92       '|..'
        LDAA    patch_upload_tmp                    ;FA8F: 96 92          '..'
        CMPA    #$18                     ;FA91: 81 18          '..'
        BNE     ZFA82                    ;FA93: 26 ED          '&.'
        LDAB    opn_ch                    ;FA95: D6 86          '..'
        ADDB    #$B0                     ;FA97: CB B0          '..'
        LDAA    ,X                       ;FA99: A6 00          '..'
        JSR     opn_write                    ;FA9B: BD F4 90       '...' fb/conn
        LDX     unk_M00BA                    ;FA9E: DE BA          '..'
        LDAA    $04,X                    ;FAA0: A6 04          '..'
        STAA    tl_op1                    ;FAA2: 97 A2          '..'
        LDAA    $05,X                    ;FAA4: A6 05          '..'
        STAA    tl_op3                    ;FAA6: 97 A4          '..'
        LDAA    $06,X                    ;FAA8: A6 06          '..'
        STAA    tl_op2                    ;FAAA: 97 A3          '..'
        LDAA    $07,X                    ;FAAC: A6 07          '..'
        STAA    tl_op4                    ;FAAE: 97 A5          '..'
        LDAA    $18,X                    ;FAB0: A6 18          '..'
        ANDA    #$07                     ;FAB2: 84 07          '..'
        LDX     #fb_algo_base                   ;FAB4: CE 00 93       '...'
        JSR     add_opn_ch_x                    ;FAB7: BD F7 1D       '...'
        STAA    ,X                       ;FABA: A7 00          '..'
        LDAA    tl_op1                    ;FABC: 96 A2          '..'
        LDX     #tl_op1_base                   ;FABE: CE 00 96       '...'
        JSR     add_opn_ch_x                    ;FAC1: BD F7 1D       '...'
        STAA    ,X                       ;FAC4: A7 00          '..'
        LDAA    tl_op2                    ;FAC6: 96 A3          '..'
        LDX     #tl_op2_base                   ;FAC8: CE 00 99       '...'
        JSR     add_opn_ch_x                    ;FACB: BD F7 1D       '...'
        STAA    ,X                       ;FACE: A7 00          '..'
        LDAA    tl_op3                    ;FAD0: 96 A4          '..'
        LDX     #tl_op3_base                   ;FAD2: CE 00 9C       '...'
        JSR     add_opn_ch_x                    ;FAD5: BD F7 1D       '...'
        STAA    ,X                       ;FAD8: A7 00          '..'
        LDAA    tl_op4                    ;FADA: 96 A5          '..'
        LDX     #tl_op4_base                   ;FADC: CE 00 9F       '...'
        JSR     add_opn_ch_x                    ;FADF: BD F7 1D       '...'
        STAA    ,X                       ;FAE2: A7 00          '..'
        RTS                              ;FAE4: 39             '9'
ZFAE5   LDAA    unk_M00BE                    ;FAE5: 96 BE          '..'
        BNE     ZFB26                    ;FAE7: 26 3D          '&='
        LDAA    #$FF                     ;FAE9: 86 FF          '..'
        LDAB    opn_timer_b                    ;FAEB: D6 8A          '..'
        SBA                              ;FAED: 10             '.'
        LSRA                             ;FAEE: 44             'D'
        LSRA                             ;FAEF: 44             'D'
        LSRA                             ;FAF0: 44             'D'
        STAA    M008B                    ;FAF1: 97 8B          '..'
        LDAB    #$0F                     ;FAF3: C6 0F          '..'
        JSR     opn_read                    ;FAF5: BD F4 AF       '...' reading tempo here for ml301
        LSRA                             ;FAF8: 44             'D'
        COMA                             ;FAF9: 43             'C'
        ANDA    #$0F                     ;FAFA: 84 0F          '..'
        CMPA    #$0A                     ;FAFC: 81 0A          '..'
        BGE     ZFB2D                    ;FAFE: 2C 2D          ',-'
        LDAB    opn_timer_b                    ;FB00: D6 8A          '..'
        CMPA    #$05                     ;FB02: 81 05          '..'
        BEQ     ZFB26                    ;FB04: 27 20          '' '
        BMI     ZFB17                    ;FB06: 2B 0F          '+.'
ZFB08   CLC                              ;FB08: 0C             '.'
        ADDB    M008B                    ;FB09: DB 8B          '..'
        BCC     ZFB0F                    ;FB0B: 24 02          '$.'
        LDAB    #$FF                     ;FB0D: C6 FF          '..'
ZFB0F   DECA                             ;FB0F: 4A             'J'
        CMPA    #$05                     ;FB10: 81 05          '..'
        BNE     ZFB08                    ;FB12: 26 F4          '&.'
        TBA                              ;FB14: 17             '.'
        BRA     ZFB28                    ;FB15: 20 11          ' .'
ZFB17   CLC                              ;FB17: 0C             '.'
        SBCB    M008B                    ;FB18: D2 8B          '..'
        BCC     ZFB1E                    ;FB1A: 24 02          '$.'
        LDAB    #$00                     ;FB1C: C6 00          '..'
ZFB1E   INCA                             ;FB1E: 4C             'L'
        CMPA    #$05                     ;FB1F: 81 05          '..'
        BNE     ZFB17                    ;FB21: 26 F4          '&.'
        TBA                              ;FB23: 17             '.'
        BRA     ZFB28                    ;FB24: 20 02          ' .'
ZFB26   LDAA    opn_timer_b                    ;FB26: 96 8A          '..'
ZFB28   LDAB    #$26                     ;FB28: C6 26          '.&'
        JSR     opn_write                    ;FB2A: BD F4 90       '...' timer b
ZFB2D   RTS                              ;FB2D: 39             '9'
ml301_setup_next_note_trk1   LDX     track1_loc_word                    ;FB2E: DE 80          '..'
        LDAA    ,X                       ;FB30: A6 00          '..'
        CMPA    #$FE                     ;FB32: 81 FE          '..'
        BEQ     ZFB58                    ;FB34: 27 22          ''"'
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

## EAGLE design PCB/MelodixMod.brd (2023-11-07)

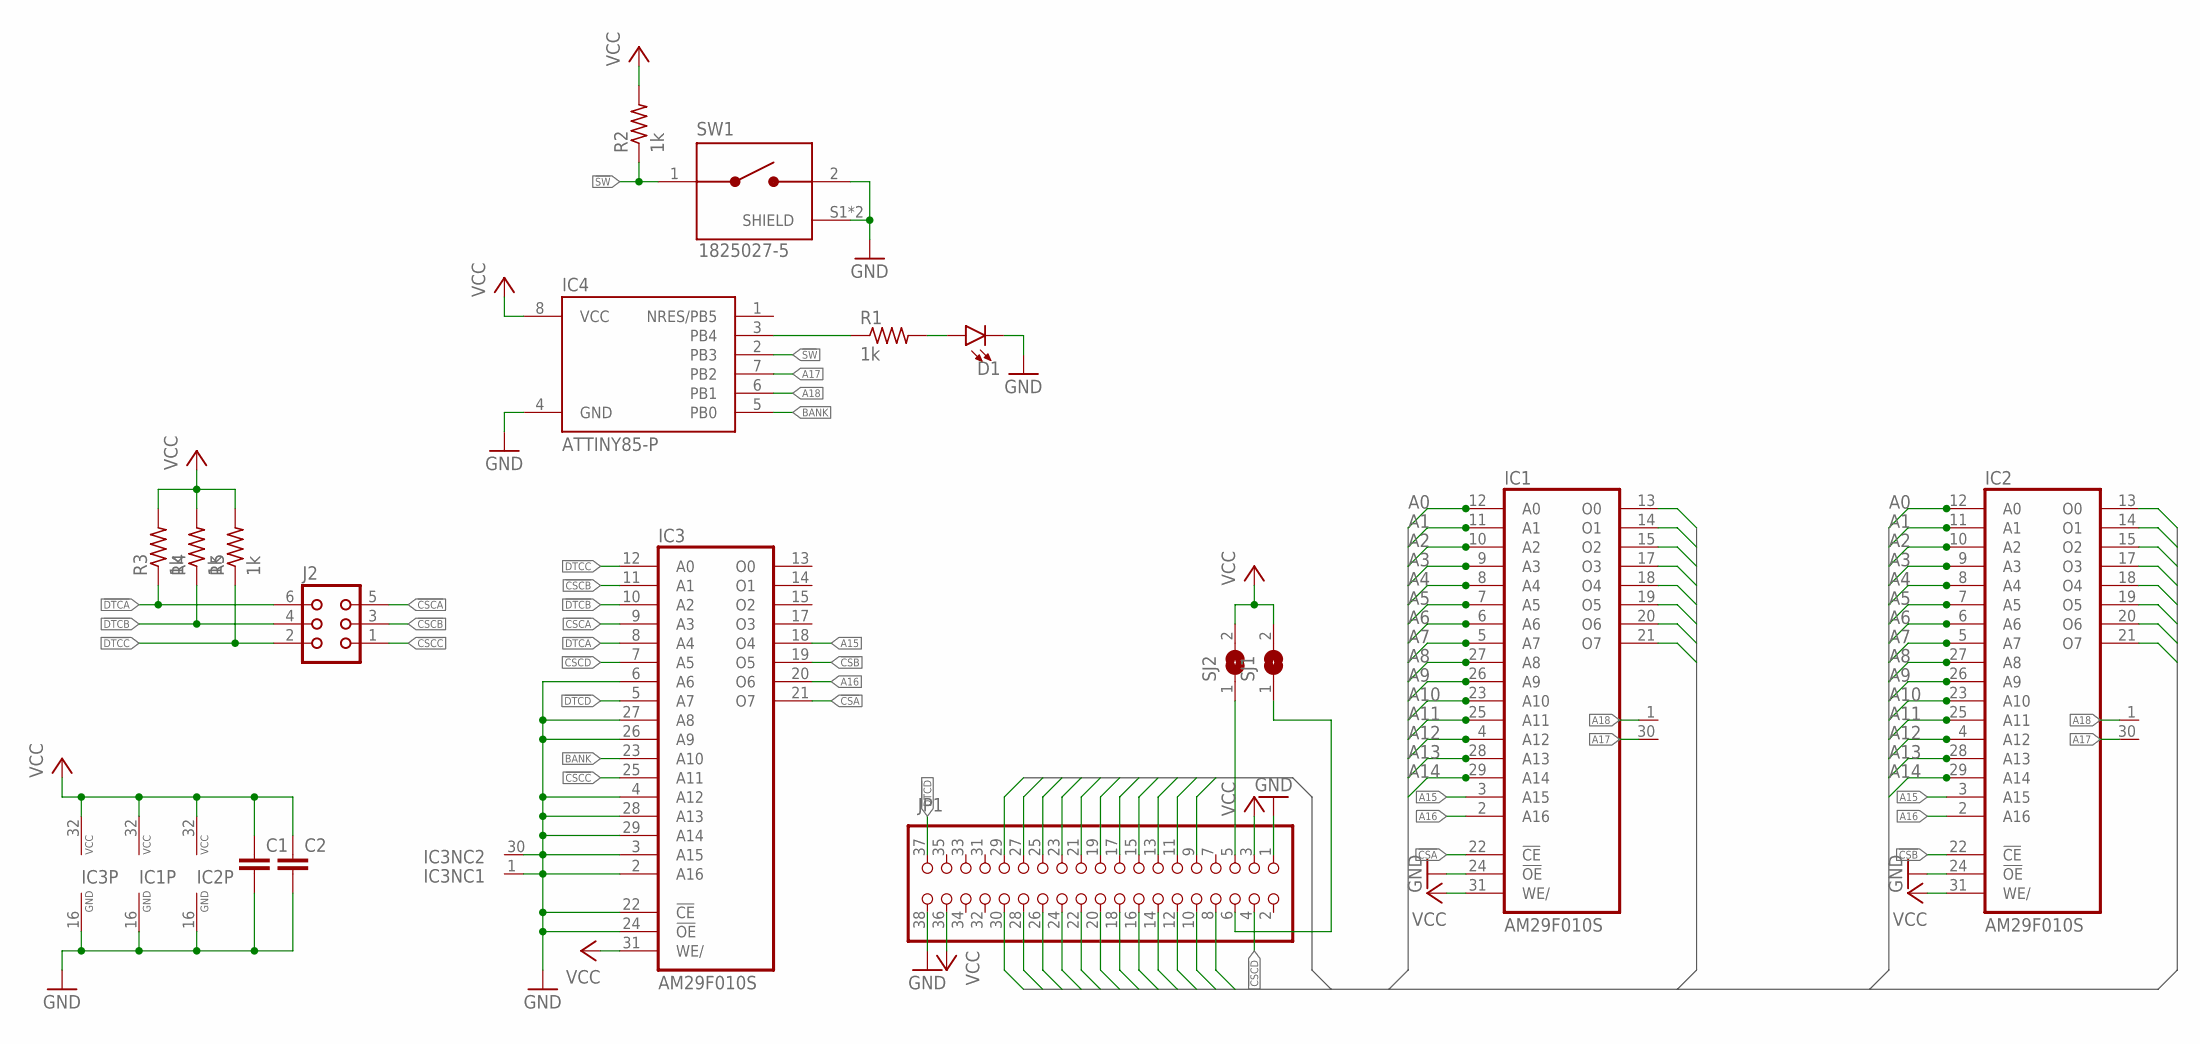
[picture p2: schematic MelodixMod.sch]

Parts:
C1, C2: C-EU025-024X044; C025-024X044
D1: LED5MM; LED_5MM
IC1, IC2, IC3: AM29F010S; PLCC-SR32
IC4: ATTINY85-P; PDIP08_300MIL
J2: CON06
JP1: FUJISOKU_B_SLOT; FUJISOKU_B_FP
R1, R2, R3, R4, R5: 1k; 0204/7
SJ1, SJ2: SJ
SW1: 1825027-5; SW_1825027-5

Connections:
!CSA: IC1.22 (!CE), IC3.21 (O7)
!CSB: IC2.22 (!CE), IC3.19 (O5)
!CSCA: IC3.9 (A3), J2.5
!CSCB: IC3.11 (A1), J2.3
!CSCC: IC3.25 (A11), J2.1
!CSCD: IC3.7 (A5), JP1.4 (!CE1)
!DTCA: IC3.8 (A4), J2.6, R3.1
!DTCB: IC3.10 (A2), J2.4, R4.1
!DTCC: IC3.12 (A0), J2.2, R5.1
!DTCD: IC3.5 (A7), JP1.37 (!CARD_DET)
!SW: IC4.2 (PB3), R2.1, SW1.1
A0: IC1.12 (A0), IC2.12 (A0), JP1.16 (A0)
A1: IC1.11 (A1), IC2.11 (A1), JP1.17 (A1)
A2: IC1.10 (A2), IC2.10 (A2), JP1.18 (A2)
A3: IC1.9 (A3), IC2.9 (A3), JP1.19 (A3)
A4: IC1.8 (A4), IC2.8 (A4), JP1.20 (A4)
A5: IC1.7 (A5), IC2.7 (A5), JP1.21 (A5)
A6: IC1.6 (A6), IC2.6 (A6), JP1.22 (A6)
A7: IC1.5 (A7), IC2.5 (A7), JP1.23 (A7)
A8: IC1.27 (A8), IC2.27 (A8), JP1.24 (A8)
A9: IC1.26 (A9), IC2.26 (A9), JP1.25 (A9)
A10: IC1.23 (A10), IC2.23 (A10), JP1.26 (A10)
A11: IC1.25 (A11), IC2.25 (A11), JP1.27 (A11)
A12: IC1.4 (A12), IC2.4 (A12), JP1.28 (A12)
A13: IC1.28 (A13), IC2.28 (A13), JP1.29 (A13)
A14: IC1.29 (A14), IC2.29 (A14), JP1.30 (A14)
A15: IC1.3 (A15), IC2.3 (A15), IC3.18 (O4)
A16: IC1.2 (A16), IC2.2 (A16), IC3.20 (O6)
A17: IC1.30 (NC), IC2.30 (NC), IC4.7 (PB2)
A18: IC1.1 (NC), IC2.1 (NC), IC4.6 (PB1)
BANK: IC3.23 (A10), IC4.5 (PB0)
D0: IC1.13 (O0), IC2.13 (O0), JP1.8 (D0)
D1: IC1.14 (O1), IC2.14 (O1), JP1.9 (D1)
D2: IC1.15 (O2), IC2.15 (O2), JP1.10 (D2)
D3: IC1.17 (O3), IC2.17 (O3), JP1.11 (D3)
D4: IC1.18 (O4), IC2.18 (O4), JP1.12 (D4)
D5: IC1.19 (O5), IC2.19 (O5), JP1.13 (D5)
D6: IC1.20 (O6), IC2.20 (O6), JP1.14 (D6)
D7: IC1.21 (O7), IC2.21 (O7), JP1.15 (D7)
GND: C1.2, C2.2, D1.K (C), IC1.16 (GND), IC1.24 (!OE), IC2.16 (GND), IC2.24 (!OE), IC3.1 (NC), IC3.2 (A16), IC3.3 (A15), IC3.4 (A12), IC3.6 (A6), IC3.16 (GND), IC3.22 (!CE), IC3.24 (!OE), IC3.26 (A9), IC3.27 (A8), IC3.28 (A13), IC3.29 (A14), IC3.30 (NC), IC4.4 (GND), JP1.1 (GND), JP1.38 (GND), SW1.2, SW1.S1 (SHIELD), SW1.S2 (SHIELD)
unnamed: IC4.3 (PB4), R1.1
unnamed: D1.A, R1.2
unnamed: JP1.5 (CE2), SJ2.1
unnamed: JP1.6 (!WE), SJ1.1
VCC: C1.1, C2.1, IC1.31 (WE/), IC1.32 (VCC), IC2.31 (WE/), IC2.32 (VCC), IC3.31 (WE/), IC3.32 (VCC), IC4.8 (VCC), JP1.3 (VCC), JP1.36 (VCC), R2.2, R3.2, R4.2, R5.2, SJ1.2, SJ2.2

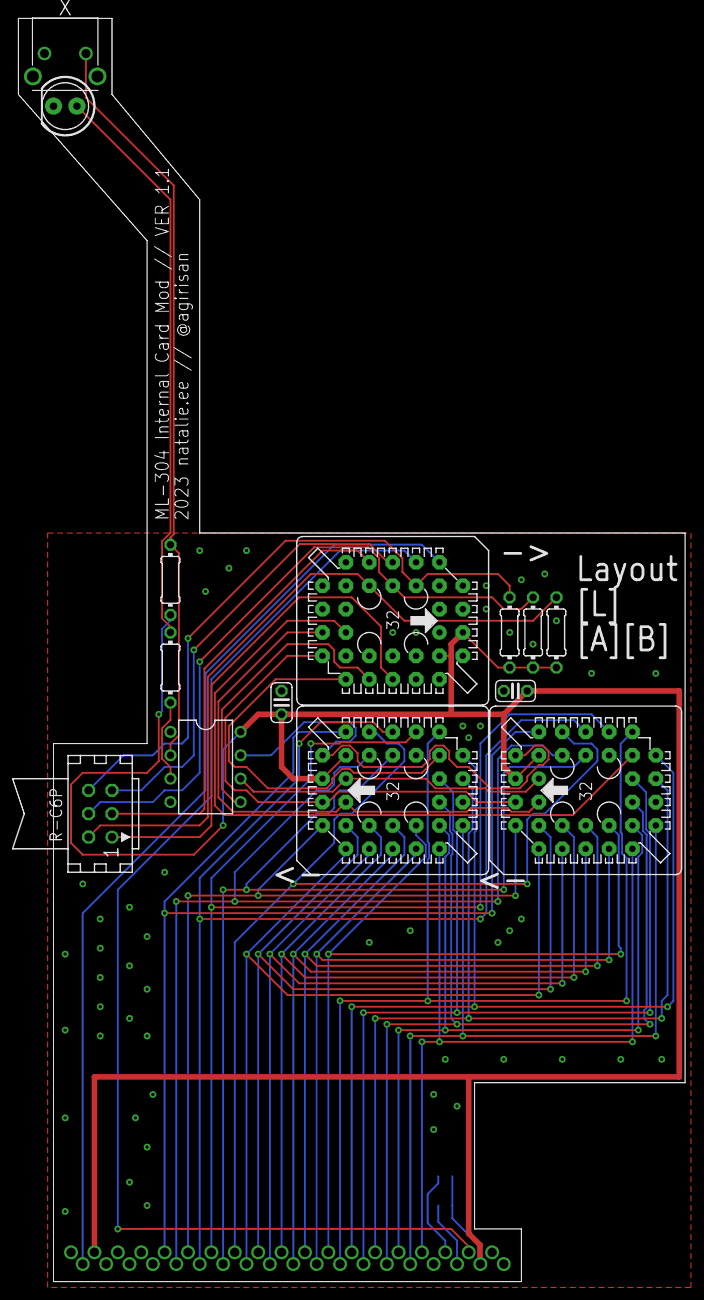
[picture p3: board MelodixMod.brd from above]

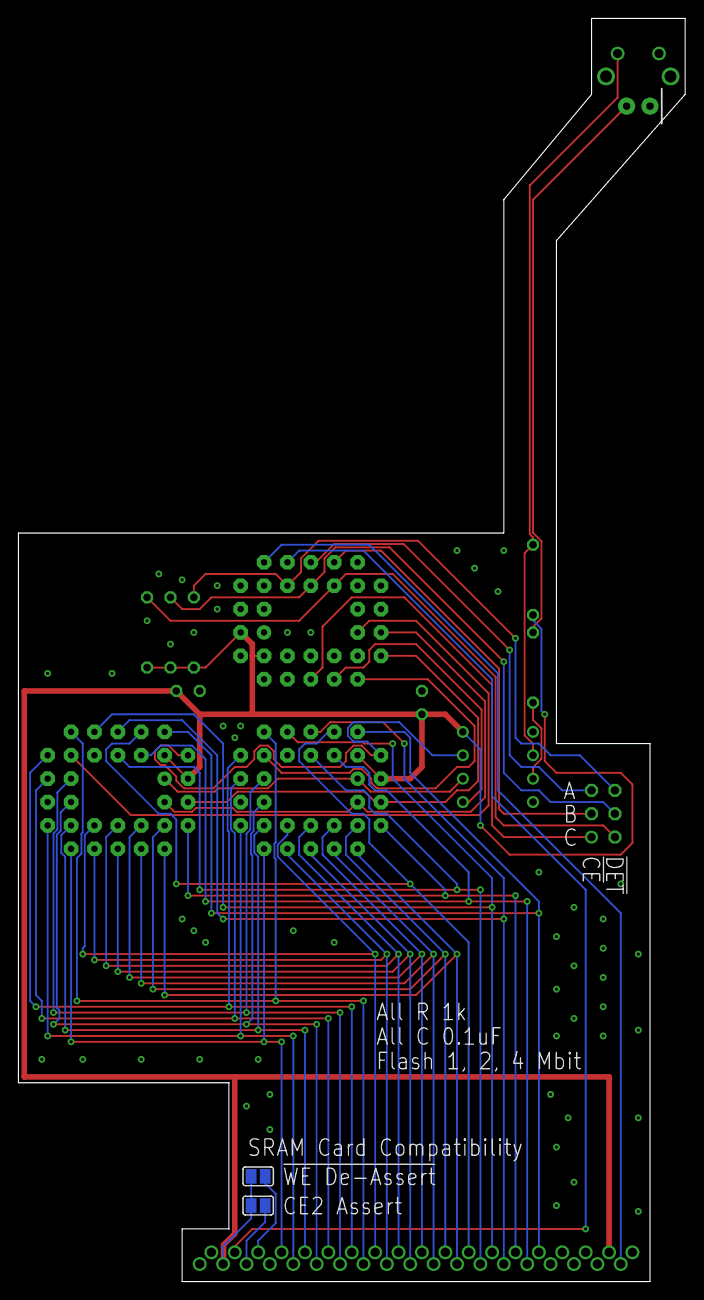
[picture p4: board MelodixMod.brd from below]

Board: 2 copper layers, 72.4 x 137.2 mm, 17 parts (2 on the bottom side), 45 nets.

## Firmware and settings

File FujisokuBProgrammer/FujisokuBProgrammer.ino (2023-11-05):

#include <digitalWriteFast.h>

//ports
//A data
//F addr lo
//K addr hi
#define PIN_N_CE1 21
#define PIN_CE2 20
#define PIN_N_WE 19
#define PIN_N_OE 18
#define PIN_LED 13

uint8_t xmbuf[128];

void setup() {
  pinMode(PIN_N_CE1, OUTPUT);
  digitalWriteFast(PIN_N_CE1, HIGH);
  pinMode(PIN_N_OE, OUTPUT);
  digitalWriteFast(PIN_N_OE, HIGH);
  pinMode(PIN_N_WE, OUTPUT);
  digitalWriteFast(PIN_N_WE, HIGH);
  pinMode(PIN_CE2, OUTPUT);
  digitalWriteFast(PIN_CE2, HIGH); //always assert this one
  DDRA = 0;
  DDRF = 0xff;
  DDRK = 0xff;
  Serial.begin(115200);
  while (!Serial);
  pinMode(PIN_LED, OUTPUT);
  digitalWriteFast(PIN_LED, LOW);
  Serial.println("started");
}

void card_write(uint16_t addr, uint8_t data) {
  digitalWriteFast(PIN_LED, HIGH);
  PORTF = addr & 0xff; //addr lo
  PORTK = addr >> 8; //addr hi
  DDRA = 0xff; //bus out
  PORTA = data; //put data on bus
  digitalWriteFast(PIN_N_CE1, LOW);
  digitalWriteFast(PIN_N_WE, LOW);
  delayMicroseconds(5);
  digitalWriteFast(PIN_N_WE, HIGH);
  delayMicroseconds(5);
  digitalWriteFast(PIN_N_CE1, HIGH);
  DDRA = 0; //bus in
  digitalWriteFast(PIN_LED, LOW);
}

uint8_t card_read(uint16_t addr) {
  digitalWriteFast(PIN_LED, HIGH);
  uint8_t val = 0;
  PORTF = addr & 0xff; //addr lo
  PORTK = addr >> 8; //addr hi
  DDRA = 0; //bus in, just in case
  digitalWriteFast(PIN_N_CE1, LOW);
  digitalWriteFast(PIN_N_OE, LOW);
  delayMicroseconds(5);
  val = PINA; //get bus
  digitalWriteFast(PIN_N_OE, HIGH);
  digitalWriteFast(PIN_N_CE1, HIGH);
  digitalWriteFast(PIN_LED, LOW);
  return val;
}

void do_read() {
  uint16_t readaddr = 0;
  uint8_t readcycle = 1;
  bool eotacked = false;
  bool started = false;
  while (1) {
    if (!Serial.available()) continue;
    char r = Serial.read();
    if (r == 0x06 || (!started && r == 0x15)) { //ack, nak if not started
      started = true;
      if (readaddr == 32768) {
        if (!eotacked) {
          Serial.write(0x04);
          eotacked = true;
          continue;
        } else {
          Serial.write(0x17);
          return;
        }
      }
      uint8_t ck = 0;
      Serial.write(0x01);
      Serial.write(readcycle);
      Serial.write(255-readcycle);
      for (uint8_t i=0;i<128;i++) {
        uint8_t d = card_read(readaddr++);
        ck += d;
        Serial.write(d);
      }
      Serial.write(ck);
      readcycle++;
    } else if (r == 'C') {
      Serial.write(0x15); //nak 16bit mode
    }
  }
}

void do_write() {
  uint8_t recvmode = 0;
  uint8_t cyc = 1;
  uint8_t recvcyc1 = 0;
  uint8_t recvcyc2 = 0;
  uint8_t gotdata = 0;
  uint8_t ck = 0;
  uint32_t lastdata = millis();
  uint8_t myck = 0;
  uint16_t cardpos = 0;
  //0 waiting for first block
  //1 waiting for cyc 1
  //2 waiting for cyc 2
  //3 getting data
  //4 waiting for checksum
  //5 waiting for next block
  while (1) {
    if (recvmode == 0) {
      Serial.write(0x15);
      delay(500);
    } else {
      if (millis() - lastdata >= 1000) {
        Serial.write(0x15);
        recvmode = 5;
        lastdata = millis();
      }
    }
    if (Serial.available()) {
      uint8_t r = Serial.read();
      lastdata = millis();
      if (recvmode == 0 || recvmode == 5) {
        if (r == 0x01) { //soh
          recvmode = 1;
          myck = 0;
          gotdata = 0;
        } else if (r == 0x04) { //eot
          Serial.write(0x06);
          return; //hack ??????
        } else if (r == 0x17) { //etb
          Serial.write(0x06);
          return;
        }
      } else if (recvmode == 1) {
        recvcyc1 = r;
        recvmode = 2;
      } else if (recvmode == 2) {
        recvcyc2 = r;
        recvmode = 3;
      } else if (recvmode == 3) {
        xmbuf[gotdata++] = r;
        myck += r;
        if (gotdata == 128) {
          recvmode = 4;
        }
      } else if (recvmode == 4) {
        ck = r;
        if (ck != myck) {
          Serial.write(0x15);
        } else if (recvcyc1 != cyc) {
          Serial.write(0x15);
        } else if (recvcyc2 != 255-cyc) {
          Serial.write(0x15);
        } else {
          for (uint8_t i=0;i<128;i++) {
            card_write(cardpos++, xmbuf[i]);
          }
          Serial.write(0x06);
          cyc++;
        }
        recvmode = 5;
      }
    }
  }
}

void loop() {
  if (Serial.available()) {
    char r = Serial.read();
    if (r == '?') {
      Serial.println("r - enter read mode");
      Serial.println("w - enter write mode");
      Serial.println("z - erase card with all 00");
      Serial.println("v - verify card is fully readable and writable");
    } else if (r == 'r') {
      Serial.println("going into read mode, begin xmodem transfer now");
      do_read();
    } else if (r == 'w') {
      Serial.println("going into write mode, begin xmodem transfer now");
      do_write();
    } else if (r == 0x0d || r == 0x0a) {
    } else if (r == 'z') {
      Serial.println("zeroing");
      for (uint16_t i=0;i<32768;i++) {
        card_write(i, 0);
      }
      Serial.println("done");
    } else if (r == 'v') {
      Serial.println("writing 1/2...");
      for (uint16_t i=0;i<32768;i++) {
        card_write(i, 0x55);
      }
      Serial.println("remove card, then press any key");
      while (!Serial.available());
      Serial.read();
      card_write(0, 0x00);
      Serial.println("reinsert card, then press any key");
      while (!Serial.available());
      Serial.read();
      Serial.println("verifying 1/2...");
      for (uint16_t i=0;i<32768;i++) {
        if (card_read(i) != 0x55) {
          Serial.println("fail!!!");
          return;
        }
      }
      Serial.println("writing 2/2...");
      for (uint16_t i=0;i<32768;i++) {
        card_write(i, 0xaa);
      }
      Serial.println("remove card, then press any key");
      while (!Serial.available());
      Serial.read();
      card_write(0, 0x00);
      Serial.println("reinsert card, then press any key");
      while (!Serial.available());
      Serial.read();
      Serial.println("verifying 2/2...");
      for (uint16_t i=0;i<32768;i++) {
        if (card_read(i) != 0xaa) {
          Serial.println("fail!!!");
          return;
        }
      }
      Serial.println("verify ok");
    }
  }
}

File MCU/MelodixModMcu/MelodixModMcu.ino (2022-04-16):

#define FLASH_MBITS 2 //1, 2, or 4
#define HAS_DUAL_FLASH //comment out for single flash ic

#define PIN_BANK 0
#define PIN_A18 1
#define PIN_A17 2
#define PIN_SW 3 //active low
#define PIN_LED 4

#define STATE_IDLE 0
#define STATE_WAITKEYUP 1
#define STATE_WAITKEYTM 2

#include <EEPROM.h>

uint8_t current_state = 0;
uint8_t current_bank = 0;
uint8_t new_bank = 0;
uint32_t state_time = 0;
#ifdef HAS_DUAL_FLASH
uint8_t max_bank = (FLASH_MBITS*2);
#else
uint8_t max_bank = FLASH_MBITS;
#endif

void set_state(uint8_t state) {
  current_state = state;
  state_time = millis();
}

void set_bank(uint8_t bank) {
  digitalWrite(PIN_A17, bank&(1<<0));
  digitalWrite(PIN_A18, bank&(1<<1));
  #ifdef HAS_DUAL_FLASH
  digitalWrite(PIN_BANK, bank&FLASH_MBITS);
  #endif
  current_bank = bank;
  new_bank = bank;
}

bool is_eeprom_inited() {
  if (EEPROM.read(0) != 0x13) return false;
  if (EEPROM.read(1) != 0x37) return false;
  if (EEPROM.read(2) != 0xba) return false;
  if (EEPROM.read(3) != 0xbe) return false;
  if (EEPROM.read(4) >= max_bank) return false;
  return true;
}

void save_bank() {
  EEPROM.write(4, current_bank);
}

void load_set_bank() {
  set_bank(EEPROM.read(4));
}

void init_eeprom() {
  EEPROM.write(0, 0x13);
  EEPROM.write(1, 0x37);
  EEPROM.write(2, 0xba);
  EEPROM.write(3, 0xbe);
  save_bank();
}

void set_led(bool on) {
  digitalWrite(PIN_LED, on);
}

void blink_x(uint8_t times) {
  while (times --> 0) {
    set_led(true);
    delay(250);
    set_led(false);
    delay(250);
  }
}

void setup_io() {
  pinMode(PIN_A17, OUTPUT);
  pinMode(PIN_A18, OUTPUT);
  pinMode(PIN_BANK, OUTPUT);
  pinMode(PIN_SW, INPUT_PULLUP);
  pinMode(PIN_LED, OUTPUT);

  digitalWrite(PIN_A17, LOW);
  digitalWrite(PIN_A18, LOW);
  digitalWrite(PIN_BANK, LOW);
  digitalWrite(PIN_LED, LOW);
}

void setup() {
  setup_io();
  if (!is_eeprom_inited()) {
    set_bank(0);
    init_eeprom();
  } else {
    load_set_bank();
  }
  blink_x(current_bank+1);
}

bool is_key_pressed() {
  return (digitalRead(PIN_SW) == LOW);
}

void handle_keypress() {
  if (is_key_pressed()) {
    set_led(true);
    if (current_state != STATE_WAITKEYTM) {
      new_bank = 0;
    } else if (new_bank == max_bank) {
      new_bank = 0;
    } else {
      new_bank++;
    }
    set_state(STATE_WAITKEYUP);
  }
}

void loop() {
  switch (current_state) {
    case STATE_WAITKEYUP:
      if (is_key_pressed()) {
        set_state(STATE_WAITKEYUP); //update timestamp
      } else {
        if (millis() - state_time >= 30) { //debounce
          set_led(false);
          set_state(STATE_WAITKEYTM);
        }
      }
      break;
    
    case STATE_WAITKEYTM:
      if (millis() - state_time >= 2000) {
        set_state(STATE_IDLE);
        set_bank(new_bank);
        save_bank();
        blink_x(current_bank+1);
      }
    case STATE_IDLE:
    default:
      handle_keypress();
      break;
  }
}

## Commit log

2022-04-16 Add chip select/bank switching logic
2023-11-07 Add v1.1 PCB
    [MelodixMod.brd, MelodixMod.sch]
2023-11-07 Add PCB spacer 3D design files
    [MelodixModPCBSpacer.scad, MelodixModPCBSpacer.stl]
2024-06-29 Start using f9dasm properly, deprecate old text find-and-replace disassembly
    [mcu.asm]
2024-07-05 Disassembly: fix hardware info
    [mcu.asm]
2024-07-09 Disassembly: Fix typo'd address for comment
    [mcu.asm]
2024-07-10 Disassembly: Correct constants on LDX instructions
    [mcu.asm]

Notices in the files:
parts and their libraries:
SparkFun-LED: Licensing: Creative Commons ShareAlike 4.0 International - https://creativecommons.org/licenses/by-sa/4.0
